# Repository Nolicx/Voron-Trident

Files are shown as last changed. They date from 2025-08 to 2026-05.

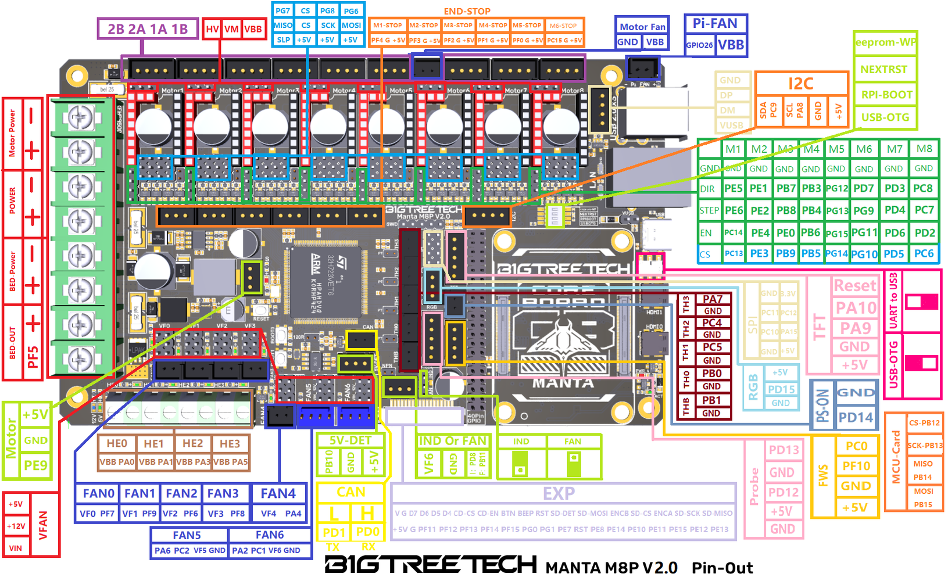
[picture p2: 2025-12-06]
BIGTREETECH MANTA M8P V2-0 PinOut.png

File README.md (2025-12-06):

# Voron Trident Formbot Kit

[Kit Website](https://www.formbot3d.com/products/voron-trident-r1-pro-corexy-3d-printer-kit-with-best-quality-parts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)

# Overview

* [Build Notes](https://github.com/FORMBOT/Voron-Trident/tree/main/Build%20Notes)
* [Firmware Flashing](https://github.com/FORMBOT/Voron-Trident/tree/main/Firmware%20Flashing)
* [Config Setup and Initial Startup](https://github.com/FORMBOT/Voron-Trident/tree/main/Config)
* Maintenance
* [STLs](https://github.com/FORMBOT/Voron-Trident/tree/main/STL)
* Printer Tuning
* Printer Testing

## CAN Network Issue
* https://github.com/systemd/systemd/issues/30947
* https://github.com/linux-can/can-utils/issues/68

## CAN Setup
* https://drklipper.de/doku.php?id=klipper_faq:klipper_0_auf_100:btt_cb1_manta_m8p_sb2209

## Voronica Config
* https://github.com/cee-wals/voronica-configs/blob/main/voronica-bigtreetech-manta-m8p-voron2.cfg

## Manta M8P V2.0 Pins
* https://meltbro.de/images/product_images/original_images/BIGTREETECH%20MANTA%20M8P%20V2-0%20PinOut.png

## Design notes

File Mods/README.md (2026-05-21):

# Voron Trident Mods

## Gridfinity holder for Voron printers (2020 extrusion)

### Gridfinity holder for Voron printers (2020 extrusion)
[Printables](https://www.printables.com/model/175108-gridfinity-holder-for-voron-printers-2020-extrusion)

* Gridfinity-Behälter an 2020-Profilen befestigen — modulares Organizer-System für Werkzeug und Kleinteile.

### Gridfinity mount for 2020 extrusions
[Printables](https://www.printables.com/model/431489-gridfinity-mount-for-2020-extrusions-voron-printer)

* ✅ installiert
* Alternativer Gridfinity-Mount für 2020-Profile, speziell für Voron-Drucker ausgelegt.

---

## Panels

### Voron 2.4/Trident Magnetic Panels with Magnet Inserts
[Printables](https://www.printables.com/model/775808-voron-24r2trident-magnetic-panels-with-magnet-inse)

* ✅ installiert
* Seitenpanele mit Magneten statt Clips — lassen sich schnell und werkzeuglos abnehmen.

### Sturdy Print-in-Place Panel Latch for 2020 Extrusion
[Printables](https://www.printables.com/model/1042802-sturdy-print-in-place-panel-latch-for-2020-extrusi/related)

* Robuster Print-in-Place Panel-Riegel für 2020-Profile als Alternative zu Clips.

---

## Magnetic Hinges

### Voron Magnetic Door Hinges Enhanced
[Printables](https://www.printables.com/model/899914-voron-magnetic-door-hinges-enhanced)

* ✅ installiert
* Verbesserte Türscharniere mit Magneten für einen saubereren Öffnungs- und Schließmechanismus.

---

## Frame

### Parametric Voron Frame Brace
[Printables](https://www.printables.com/model/1270452-parametric-voron-frame-brace)

* Parametrische Rahmenversteifung an den Ecken — reduziert Vibrationen und verbessert die Resonanzqualität.

### 2020 Top Corner for Voron 2.4 / Trident
[Printables](https://www.printables.com/model/1354277-2020-top-corner-for-voron-24-trident)

* Ersatz-Eckverbinder für die oberen 2020-Profile.

### Voron Simplified Corners
[Printables](https://www.printables.com/model/1643589-voron-simplified-corners)

* Vereinfachte Ecken für den Voron-Rahmen — cleaner Look, gleiche Funktion.

---

## Auxiliary Fans

### Auxiliary Fans
[Thingiverse](https://www.thingiverse.com/thing:6122197)

* ✅ installiert
* Zusätzliche Lüfter zur Kammerbelüftung, montiert an DIN-Schienen via Klipper Expander gesteuert.

### Klipper Expander
[GitHub](https://github.com/VoronDesign/Voron-Hardware/tree/master/Klipper_Expander)

* ✅ installiert
* Erweiterungsboard für zusätzliche Klipper-Ausgänge (z. B. Lüftersteuerung).

### Klipper Expander DIN Rail Adapter
[Printables](https://www.printables.com/model/425248-klipper-expander-din-rail-adapter)

* ✅ installiert
* DIN-Schienen-Adapter für den Klipper Expander.

### PCB DIN Clip x3 (Formbot)
[GitHub](https://github.com/FORMBOT/Voron-Trident/blob/main/STL/ElectronicsBay/pcb_din_clip_x3.stl)

* ✅ installiert
* DIN-Schienen-Clips zur Befestigung von PCBs (Formbot-spezifisch, 3er-Set).

---

## Lighting

### Voron Daylight
[GitHub](https://github.com/VoronDesign/Voron-Hardware/blob/master/Daylight/README.md)

* ✅ installiert
* Voron Daylight LED-Leisten für gleichmäßige Kammerausleuchtung.

---

## Exhaust Cover

### Voron 2.4 Exhaust Cover
[Printables](https://www.printables.com/model/412144-voron-24-exhaust-cover)

* ✅ installiert
* Abdeckung für den Abluftbereich — schließt die Öffnung sauber ab wenn kein Filter verbaut ist.

---

## Preloaded Lead Screw Nuts

### Voron Trident Z-Axis Mods for Preloaded Lead Screw Nuts
[Printables](https://www.printables.com/model/1232008-voron-trident-z-axis-mods-for-preloaded-lead-screw)

* ✅ installiert
* Z-Achsen-Spindelmuttern mit Federvorspannung — eliminiert Spiel in der Z-Achse für präzisere erste Schicht.

---

## Thermistor Mounts

### NTC 100k 3950 Glass Thermistor Mount (2020 extrusion)
[Printables](https://www.printables.com/model/805687-ntc-100k-3950-glass-thermistor-mount-2020-extrusio)

* Halterung für NTC-100k-Glasthermistor an 2020-Profil — Kammertemperaturmessung.

### NTC 100k 3950 Glass Thermistor Chamber Sensor Mount
[Printables](https://www.printables.com/model/1330198-ntc-100k-3950-glass-thermistor-chamber-sensor-moun)

* ✅ installiert
* Montagehalter für NTC-100k-Glasthermistor als Kammertemperatursensor.

### Voron CW2 Thermistor Holder PCB Cover
[Printables](https://www.printables.com/model/536989-voron-cw2-thermistor-holder-pcb-cover)

* ✅ installiert
* PCB-Abdeckung mit integriertem Thermistorhalter für das Clockwork2-Extruder-System.

---

## Build Plate Stopper

### Voron 2.4 Flex Plate Stops
[MakerWorld](https://makerworld.com/en/models/109337-voron-2-4-flex-plate-stops?from=search)

* ✅ installiert
* Anschläge für die Flex-/PEI-Platte — sorgen für reproduzierbare Positionierung beim Einlegen.

### Trident PEI Plate Mounting Slot
[MakerWorld](https://makerworld.com/en/models/1024379-trident-pei-plate-mounting-slot?from=search#profileId-1006303)

* ✅ installiert
* Einschubführung für PEI-Druckplatten am Voron Trident.

---

## Inverted Electronics

### Inverted Electronics
[Voron Mods](https://mods.vorondesign.com/details/pXkXHVIUbqSWqQKJISczw)

* ✅ installiert
* Elektronikboden wird umgekehrt eingebaut — bessere Zugänglichkeit und Wärmetrennung vom Druckraum.

### Trident Inverted Electronics Deck Handle
[Printables](https://www.printables.com/model/933809-trident-inverted-electronics-deck-handle)

* ✅ installiert
* Griff für den invertierten Elektronikboden — erleichtert das Entnehmen des Decks.

### DIN Rail Wire Channel Support
[Printables](https://www.printables.com/model/782718-din-rail-wire-channel-support-voron-trident-invert)

* ✅ installiert
* Kabelkanalhalter für DIN-Schiene bei invertiertem Elektronikboden.

### Trident Inverted Electronics Slip-In Bracket
[Printables](https://www.printables.com/model/883096-voron-trident-inverted-electronics-slip-in-bracket)

* ✅ installiert
* Einschubhalter für Elektronikkomponenten beim invertierten Deck.

### Spacer for Inverted Electronics (Noctua)
[Printables](https://www.printables.com/model/253265-voron-trident-spacer-for-inverted-electronics-noct)

* ✅ installiert
* Abstandshalter für Noctua-Lüfter beim invertierten Elektronikboden.

### BTT M8P V2.0 Cooling 2x4010
[Printables](https://www.printables.com/model/891446-btt-m8p-v20-cooling-2x4010)

* ✅ installiert (ersetzt durch das untere)
* Kühlgehäuse für das BTT Manta M8P mit 2× 40-mm-Lüftern.

### Manta Rays – BTT Manta M8P Fan Case
[Printables](https://www.printables.com/model/1181320-manta-rays-btt-manta-m8p-fan-case/files)

* ✅ installiert
* Verbessertes Lüftergehäuse für das BTT Manta M8P — bevorzugte Alternative zum obigen Modell.

---

## Nozzle Scrubber

### Trident Decontaminator/Nozzle Scrubber Wiper (Bambu)
[Printables](https://www.printables.com/model/904716-trident-decontaminatornozzle-scrubber-wiper-bambu)

* Automatische Düsenreinigung für den Voron Trident — Bambu-kompatible Bürste.

### LDO Trident Mount for Decontaminator Purge Bucket
[Printables](https://www.printables.com/model/889734-ldo-trident-mount-for-decontaminator-purge-bucket)

* Befestigungshalter für den Purge-Eimer am LDO Trident.

### Voron 2.4 Bamboo A1 Brush Bucket
[Printables](https://www.printables.com/model/957985-voron-24-bamboo-a1-brush-bucket)

* ✅ installiert, Macro eingebunden
* Purge-Eimer und Düsenreiniger für den Voron 2.4 — kompatibel mit Bambu-A1-Bürste.

### Voron 2.4 Silicone Nozzle Scrubber w/ Sheet Stops
[Printables](https://www.printables.com/model/796563-voron-24-silicone-nozzle-scrubber-w-sheet-stops-be)

* Silikon-Düsenreiniger mit integrierten Sheet-Stops — das zugehörige Macro ist interessant.

---

## Bambulab Hotend

### Bambu Stealthburner Rear TAP Support
[Printables](https://www.printables.com/model/607566-bambu-stealthburner-rear-tap-support)

* ✅ installiert
* Hintere TAP-Abstützung für den Stealthburner mit Bambu-Hotend.

### Bambu Stealthburner for Stock Bambu Hotend
[Printables](https://www.printables.com/model/550394-bambu-stealthburner-for-stock-bambu-hotend)

* ✅ installiert
* Adapter um das BambuLab-Hotend im Stealthburner zu betreiben — hohe Durchflussrate, einfacher Düsenwechsel.

### CHT High Flow Nozzle for BambuLab (CNC Kitchen)
[CNC Kitchen](https://www.cnckitchen.com/blog/cht-high-flow-nozzle-for-the-bambulab-x1-amp-p1p)

* CHT High-Flow-Düse für das BambuLab-Hotend — erhöht den maximalen Volumenstrom deutlich.

---

## Camera

### HappyCam Voron 2.4 OV5640 Camera Mount
[Printables](https://www.printables.com/model/488020-happycam-voron-24-ov5640-camera-mount)

* ✅ installiert
* Kamerahalterung für OV5640-Modul zur Drucküberwachung via Mainsail/Fluidd.

### Camera Mount (Voron Mods)
[Voron Mods](https://mods.vorondesign.com/details/RYpQW53mtem8Nj1JKqiSQ)

* Alternative offizielle Kamerahalterung aus der Voron-Mods-Sammlung.

---

## FilamATrix

### FilamATrix
[GitHub](https://github.com/thunderkeys/FilamATrix/tree/main)

* Multi-Material-Filamentwechsler — ermöglicht automatischen Filamentwechsel für mehrfarbige Drucke.

---

## Build Plate Holder

### Steel Sheet Holder for Voron 2.4 / Trident
[Printables](https://www.printables.com/model/368691-steel-sheet-holder-for-voron-24-voron-trident-v0)

* Externe Halterung für Reservedruckplatten außen am Drucker.

---

## Filament Runout Sensor

### Voron Filament Runout Sensor
[Printables](https://www.printables.com/model/742887-voron-filament-runout-sensor)

* Sensor erkennt Filamentende und pausiert den Druck automatisch.

---

## HULA

### HULA v1.0 for Voron Printers
[Printables](https://www.printables.com/model/898357-hula-v10-for-voron-printers)

* ✅ installiert
* Hochperformanter Filamentantrieb — verbesserte Gripper-Geometrie für zuverlässigen Vorschub bei hohen Druckgeschwindigkeiten.

### HULA Voron
[GitHub](https://github.com/thrutheframe/HULA_Voron)

* ✅ installiert
* GitHub-Repository zum HULA-Extruder mit Dokumentation und STLs.

---

## Stepper Decoupler

### Voron Trident Stepper Decoupler
[Printables](https://www.printables.com/model/430168-voron-trident-stepper-decoupler)

* ✅ installiert
* Entkoppler zwischen Z-Stepper und Spindel — ermöglicht freies Absinken des Bettes beim Homing ohne Motorwiderstand.

### Double Shear Mounts
[GitHub](https://github.com/gdsolar/Printer-Mods/tree/main/Voron/Double_Shear_Mounts)

* Beidseitig gelagerte Motorhalterungen für reduzierte Biegebelastung auf den Motorwellen.

---

## Front Idlers

### Voron BFI Aesthetic Trident Remix
[Printables](https://www.printables.com/model/1024258-voron-bfi-asthetic-trident-remix)

* ✅ installiert
* Optisch überarbeitete vordere Riemenspanner — gleiche Funktion, cleaner Look.

### Voron Trident WS-1204 WobbleX
[Printables](https://www.printables.com/model/1376982-voron-trident-ws-1204-wobblex)

* WobbleX-Idler für den Voron Trident — reduziert Resonanzartefakte durch dämpfende Lagerung.

### Interfaces for WobbleX Integration
[GitHub](https://github.com/MirageC79/Interfaces-for-WobbleX-integration)

* Adapter-Interfaces zur Integration des WobbleX-Systems in bestehende Voron-Setups.

---

## Side Handles

### Voron 2.4 / Trident Side Handles
[Printables](https://www.printables.com/model/826183-voron-24-trident-side-handles)

* ✅ installiert
* Seitliche Tragegriffe — erleichtern das Anheben und Transportieren des Druckers.

---

## Spool Holders

### Trident Internal Spool Holder for 2020 Extrusion
[Printables](https://www.printables.com/model/584995-trident-internal-spool-holder-for-2020-extrusion/)

* ✅ installiert
* Interne Spulenhalter — Filament wird direkt im Drucker geführt, kurzer Bowden-Weg zum Extruder.

### Trident Simple Internal Spool Holder Bowden Guide 60°
[TeamFDM](https://www.teamfdm.com/files/file/619-trident-simple-internal-spool-holder-bowden-guide-60degrees-curved/)

* ✅ installiert
* 60°-Bowden-Guide für den internen Spulenhalter — sanfte Filamentführung zum Extruder.

### Classic Spool Holder (V2.4/Trident)
[GitHub](https://github.com/elcrni/V2.4-Trident-Spool-Holders/blob/main/STL/Classic__spool_holder.stl)

* ✅ installiert
* Klassischer Spulenhalter für Voron 2.4 und Trident.

### Voron Trident Internal Spool Bowden Tube Bracket
[Printables](https://www.printables.com/model/678821-voron-trident-internal-spool-bowden-tube-bracket/files?lang=de)

* ✅ installiert
* Haltewinkel für den Bowden-Schlauch am internen Spulenhalter.

### Locking Foldable Spool Holder
[Printables](https://www.printables.com/model/542953-locking-foldable-spool-holder-for-voron-v02-0-v0-0)

* Klappbarer Spulenhalter mit Arretierung — platzsparend wenn nicht in Benutzung.

---

## KNOMIv2

### KNOMI v2
[GitHub](https://github.com/bigtreetech/KNOMI)

* ✅ installiert
* BTT KNOMI v2 Display am Toolhead — zeigt Druckstatus, Temperaturen und Fortschritt direkt am Druckkopf an.

---

## PSU Cover

### PSU Cover
[Voron Mods](https://mods.vorondesign.com/details/jyO8bHoPTy3XUaYlXscB7w)

* Schutzabdeckung für die Netzteilklemmen — verhindert versehentlichen Kontakt mit spannungsführenden Teilen.

---

## Rainbow Serial Bumper

### Rainbow Serial Bumper
[Voron Mods](https://mods.vorondesign.com/details/dpPGVV98ROfSC1Kmu16MEg)

* Dekorativer Bumper für die Seriennummer — schützt die Serienaufschrift und wertet die Optik auf.

---

## PTFE Bowden Guide

### Voron Bowden PTFE Tube Guide Arm and CAN Bus Cable
[Printables](https://www.printables.com/model/978123-voron-bowden-ptfe-tube-guide-arm-and-canbus-cable)

* ✅ installiert
* Führungsarm für PTFE-Schlauch und CAN-Bus-Kabel — ordentliches Kabelmanagement am Toolhead.

---

## Nevermore Mount

### Trident Nevermore Bed Mount
[GitHub](https://github.com/Outrider305/Trident_Nevermore_Bed_Mount/blob/6f0d5977b592f5feb3b60df2ecaaecfb3d4709c4/STLs/Trident_Bed_Mount_Bracket_Right.stl)

* ✅ installiert
* Halterung für den Nevermore-Aktivkohlefilter am Bett — filtert VOCs und Gerüche direkt aus der Druckkammer.

---

## Formbot R1

### BTT HDMI5 V1.2 Display Mount Voron
[Printables](https://www.printables.com/model/926845-btt-hdmi5-v12-display-mount-voron)

* Halterung für das BTT HDMI5 V1.2 Display am Voron-Rahmen.

### Voron Trident Wire Cover w/ PG7 Cable Gland Adapter
[Printables](https://www.printables.com/model/326623-voron-trident-wire-cover-w-pg7-cable-gland-adapter/files)

* Kabelabdeckung mit PG7-Kabelverschraubungsadapter für sauberes Kabelmanagement.

### PG7 / Cnlinko LP-12 Mount for SB2209/SB2240
[Printables](https://www.printables.com/model/464735-pg7-cnlinko-lp-12-mount-for-sb2209-sb2240)

* Halterung für PG7- oder Cnlinko-LP-12-Steckverbinder am SB2209/SB2240.

### Voron Trident Fixed Nozzle Scrubber (Remixes)
[Printables](https://www.printables.com/model/413177-voron-trident-fixed-nozzle-scubber/remixes)

* Fester Düsenreiniger für den Voron Trident — diverse Remixes für verschiedene Setups.

---

## Clicky-Clack Fridge Door

### Clicky-Clack Fridge Door
[GitHub](https://github.com/tanaes/whopping_Voron_mods/tree/main/clickyclacky_door)

* Kühlschranktür-Umbau für den Voron — magnetisch verriegelnde Fronttür mit charakteristischem Klappmechanismus.

### Clicky-Clack Fridge Door – Voron Logo Handle
[Printables](https://www.printables.com/model/849495-clicky-clack-fridge-door-voron-logo-handle/files)

* Türgriff mit Voron-Logo für die Clicky-Clack-Tür.

### Voron Fridge Door Light Switch
[MakerWorld](https://makerworld.com/en/models/2519870-voron-fridge-door-light-switch?from=search#profileId-2772082)

* Lichtschalter-Mechanismus für die Clicky-Clack-Tür — schaltet die Kammerbeleuchtung beim Öffnen.

### Thicc Skirts for Voron Clicky-Clack Fridge Door
[Printables](https://www.printables.com/model/961366-thicc-skirts-for-voron-clicky-clack-fridge-door/)

* Verstärkte Skirts kompatibel mit dem Clicky-Clack-Tür-Umbau.

### BTT HDMI 5 Display Voron Mount (Clicky-Clack compatible)
[Printables](https://www.printables.com/model/861544-btt-hdmi-5-display-voron-mount-works-with-clicky-c/remixes)

* Display-Halterung für das BTT HDMI 5, kompatibel mit der Clicky-Clack-Tür.

### BTT HDMI5 V1.2 Display Mount Voron
[Printables](https://www.printables.com/model/926845-btt-hdmi5-v12-display-mount-voron/files)

* Offizielle Halterung für das BTT HDMI5 V1.2 Display.

---

## Skirt

### Plug-in Mesh Inserts for Voron Trident Skirts
[Printables](https://www.printables.com/model/1275963-plug-in-mesh-inserts-for-voron-trident-skirts/files)

* Einsteckbare Gitter-Einsätze für die Voron-Trident-Skirts — verbesserte Optik und Belüftung.

### Modular Mesh Inserts for Voron Fan Grille
[Printables](https://www.printables.com/model/931612-modular-mesh-inserts-for-the-voron-fan-grille/files)

* Modulare Gittereinsätze für die Voron-Lüftergitter.

---

## Wago Mounts

### Extended Wago Mount – Voron Trident
[Printables](https://www.printables.com/model/928966-extended-wago-voron-trident/files)

* Verlängerter Halter für Wago-Klemmen im Voron Trident.

### Double Wago 221-413 for 2020 Profile – Voron Trident
[Printables](https://www.printables.com/model/1716086-double-wago-221-413-for-2020-profile-voron-trident)

* Doppelhalter für Wago 221-413 Klemmen an 2020-Profilen.

### Wago Mount for Voron V0
[Printables](https://www.printables.com/model/723488-wago-mount-for-voron-v0/files)

* Wago-Klemmenhalter ursprünglich für den Voron V0, ggf. adaptierbar.

---

## Nevermore

### Nevermore Micro V6
[GitHub](https://github.com/nevermore3d/Nevermore_Micro/tree/master/V6)

* Nevermore Micro V6 — kompakter Aktivkohlefilter für die Druckkammer zur VOC- und Geruchsfilterung.

---

## General

- [Trident Mods Collection (pila81)](https://github.com/pila81/Trident_Mods)
- [Voron Build Startup](https://docs.vorondesign.com/build/startup/)
- [Voron Slicer Setup](https://docs.vorondesign.com/build/slicer/)
- [Voron Secondary Printer Tuning](https://docs.vorondesign.com/tuning/secondary_printer_tuning.html)
- [Ellis3DP Print Tuning Guide](https://ellis3dp.com/Print-Tuning-Guide/)

---

## Macros

- [Ellis3DP Useful Macros](https://ellis3dp.com/Print-Tuning-Guide/articles/index_useful_macros.html)
- [Voron 120 Decibel Macro](https://docs.vorondesign.com/community/macros/macros/120decibell.html)
- [Decontaminator Purge Bucket & Nozzle Scrubber Macro](https://github.com/edwardyeeks/VoronUsers/blob/master/printer_mods/edwardyeeks/Decontaminator_Purge_Bucket_%26_Nozzle_Scrubber/Macros/sample_nozzle_scrub_menu.cfg)
- [Voron Trident 250 Macros Config](https://github.com/rcg94/voron-trident-250-20241017/blob/main/macros.cfg)

---

## Klipper Extensions

- [klipper-virtual_leds](https://github.com/MapleLeafMakers/klipper-virtual_leds)
- [klipper-led_effect](https://github.com/julianschill/klipper-led_effect)
- [klipper_tmc_autotune](https://github.com/andrewmcgr/klipper_tmc_autotune)
- [chopper-resonance-tuner](https://github.com/MRX8024/chopper-resonance-tuner)
- [klippain-shaketune](https://github.com/Frix-x/klippain-shaketune)
- [Klipper Adaptive Meshing & Purging](https://github.com/kyleisah/Klipper-Adaptive-Meshing-Purging)

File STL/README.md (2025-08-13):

# Notes
STLs are tried to be kept up to date.
Original Repos: 
https://github.com/VoronDesign/Voron-Trident
https://github.com/VoronDesign/Voron-Stealthburner
https://github.com/VoronDesign/Voron-Tap
https://github.com/bigtreetech/EBB/tree/master/EBB%20SB2209%20CAN%20(RP2040)
https://github.com/nevermore3d/Nevermore_Micro/tree/master/V5_Duo
and some specific parts ;)

# Filename Nomenclature

| Filename | Note |
|---|---|
| \*.stl | Base color |
| [a]\_\*.stl | Accent color |
| [o]\_\*.stl | Opaque (light doesn't penetrate) |
| [c]\_\*.stl | Clear/Translucent (light can penetrate) |

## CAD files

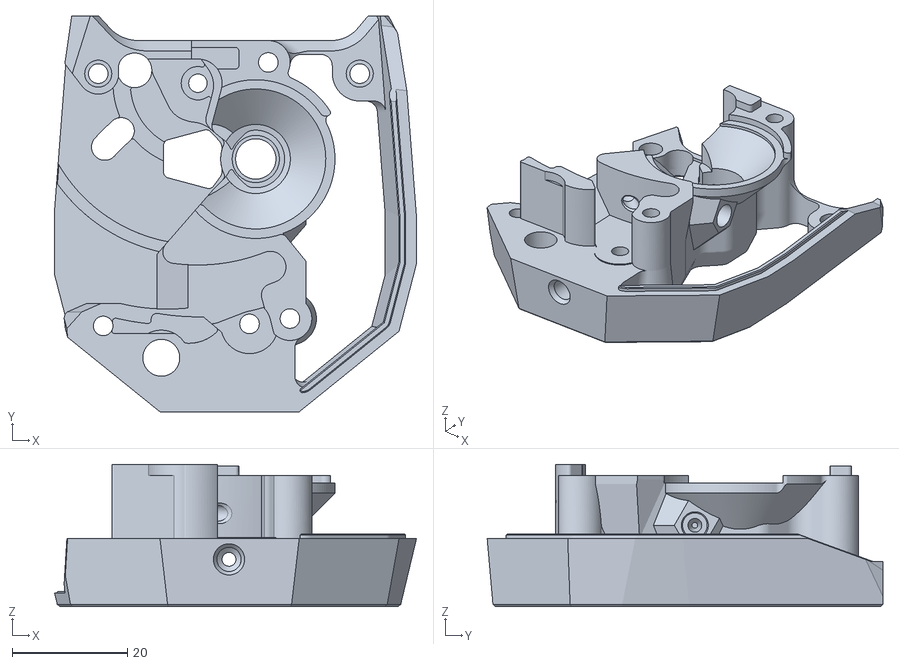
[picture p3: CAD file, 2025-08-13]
STL/Stealthburner/Clockwork2/Direct_Drive/main_body.stl
62.8 x 68.7 x 24.7

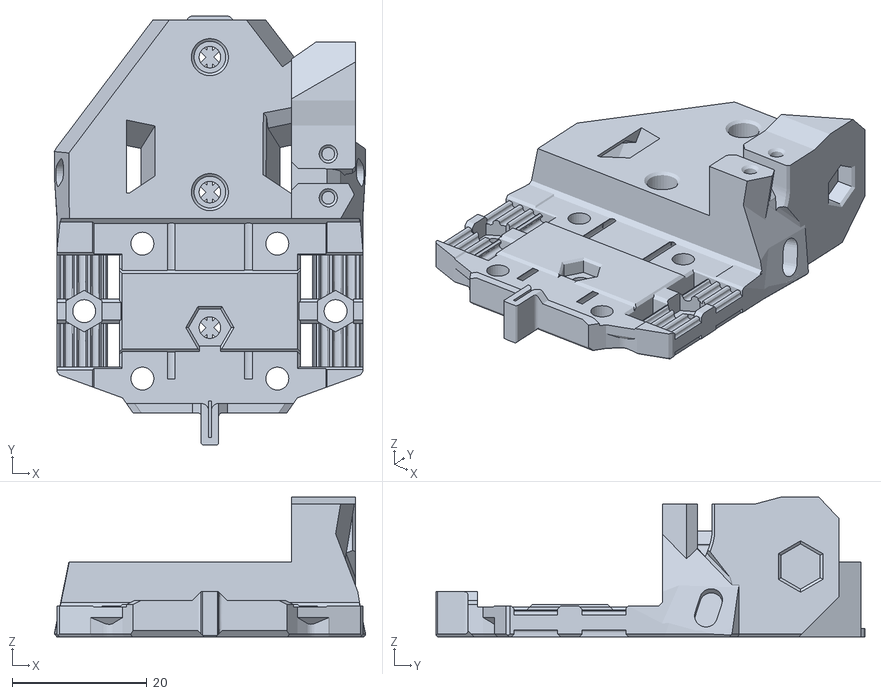
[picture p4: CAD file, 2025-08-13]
Mods/[a]_Tap_Center_r8.stl
46.2 x 63.6 x 20.7

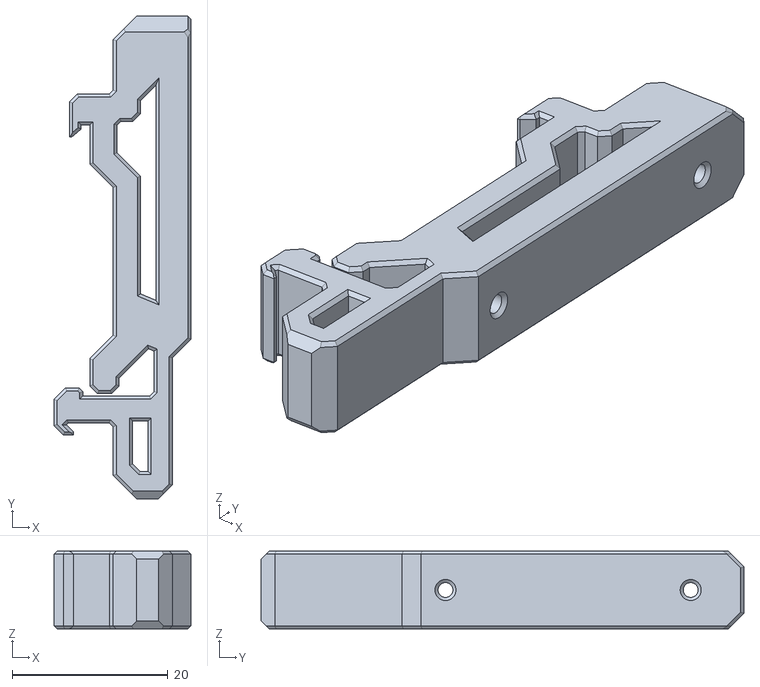
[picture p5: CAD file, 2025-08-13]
Mods/auxiliary_fans/pcb_din_clip_x3.stl
17.6 x 62.0 x 10.0

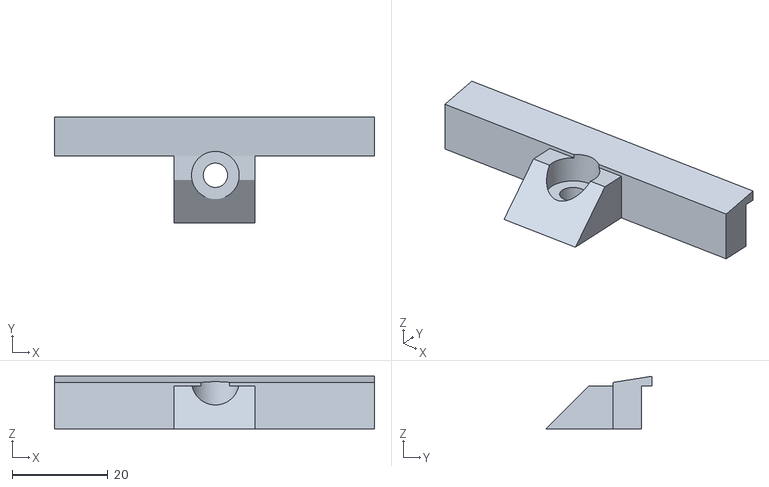
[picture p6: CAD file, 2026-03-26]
Mods/build_plate_stopper/PEI.stl
67.0 x 22.2 x 11.0

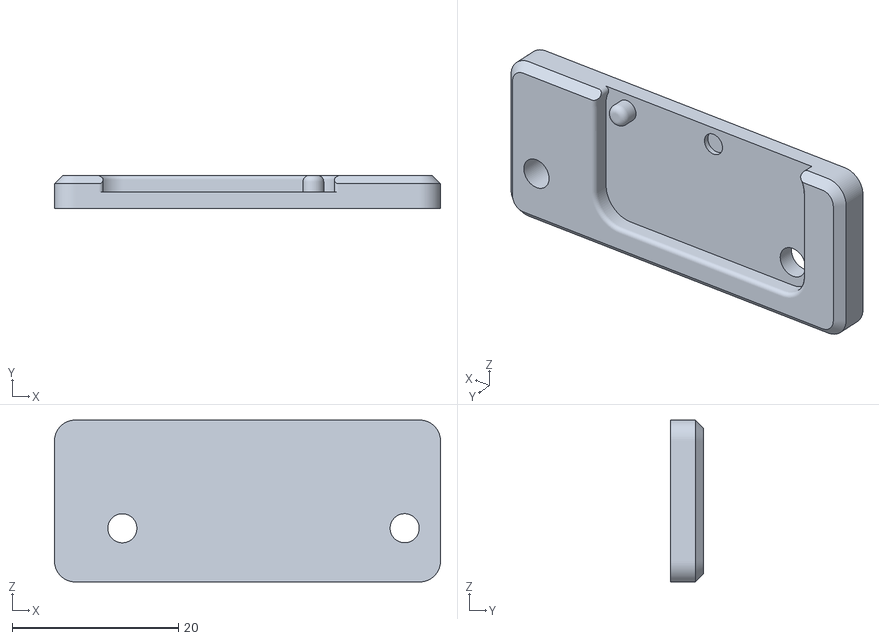
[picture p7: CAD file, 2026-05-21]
Mods/door/Voron+Fridge+Door+Light+Switch.stl
46.5 x 4.00 x 19.5

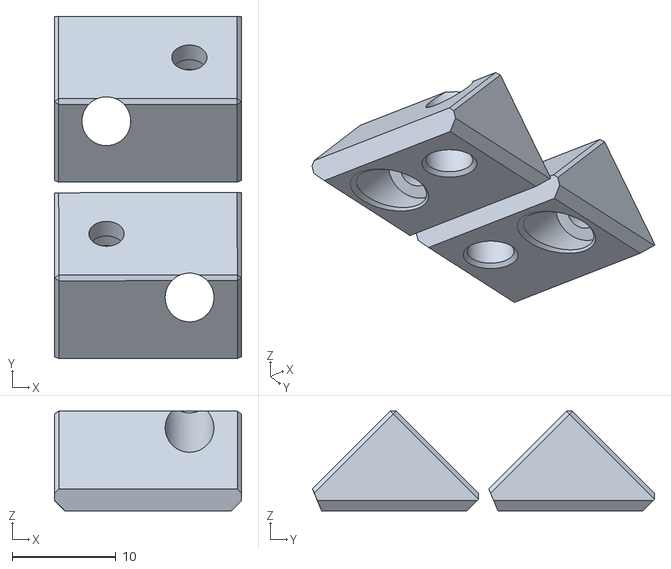
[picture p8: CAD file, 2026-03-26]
Mods/lighting/Brackets_2020.stl
18.0 x 33.0 x 9.62

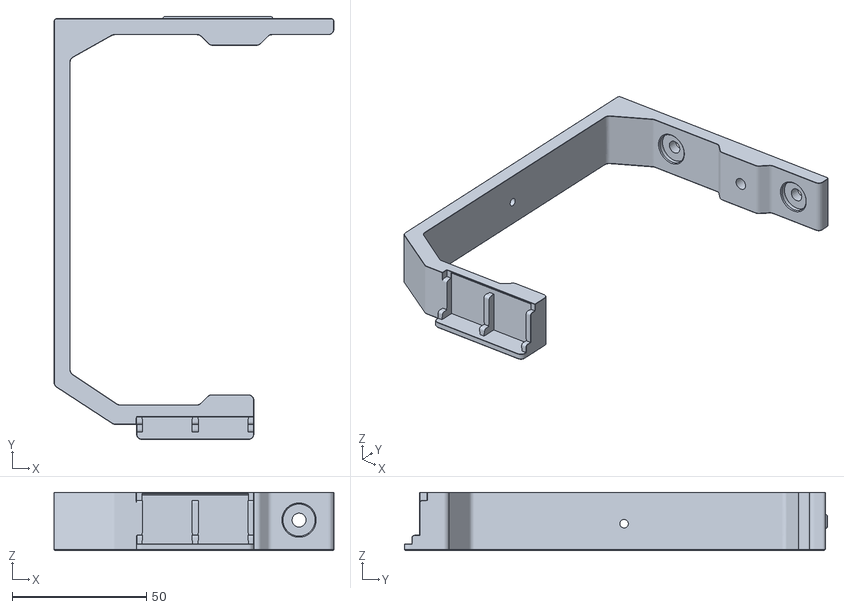
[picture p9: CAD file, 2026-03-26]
Mods/nevermore_mount_v1/Trident_Bed_Mount_Bracket_Right(1).stl
104.3 x 157.7 x 21.8

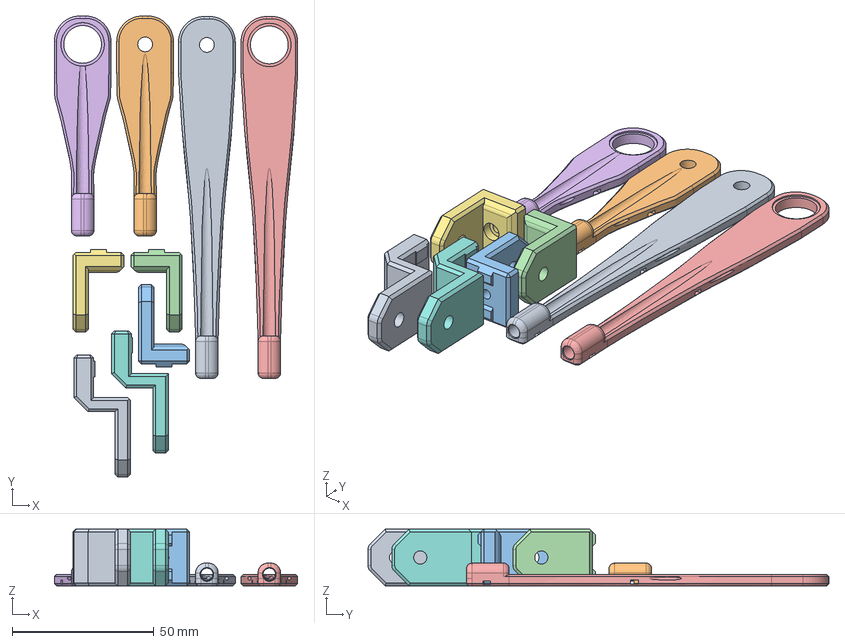
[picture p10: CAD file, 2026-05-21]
Mods/ptfe_bowden_guide/voron-bowden-ptfe-tube-guide-arm-and-canbus-cable-support-model_files/CAD/bowden_guide-v2.step
85.8 x 162.4 x 20.0 mm
Long_Arm
Mount v1
Mount
Mount_Bearing
Long Arm Bearing
Short_Arm_Bearing
Low_Mount_Bearing
Under_extrusion_mount_bearing
Under_extrusion_mount

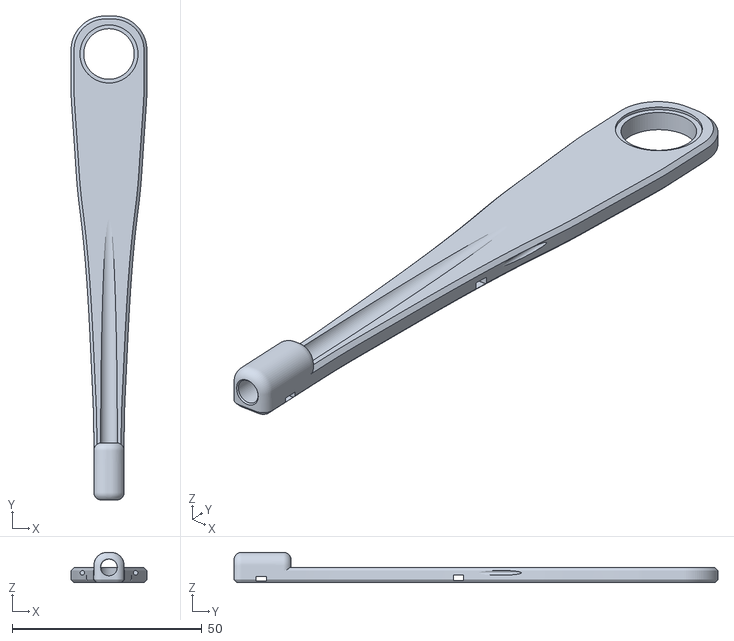
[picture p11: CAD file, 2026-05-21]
Mods/ptfe_bowden_guide/voron-bowden-ptfe-tube-guide-arm-and-canbus-cable-support-model_files/STL's/long-arm-bearing.stl
20.0 x 127.5 x 8.00

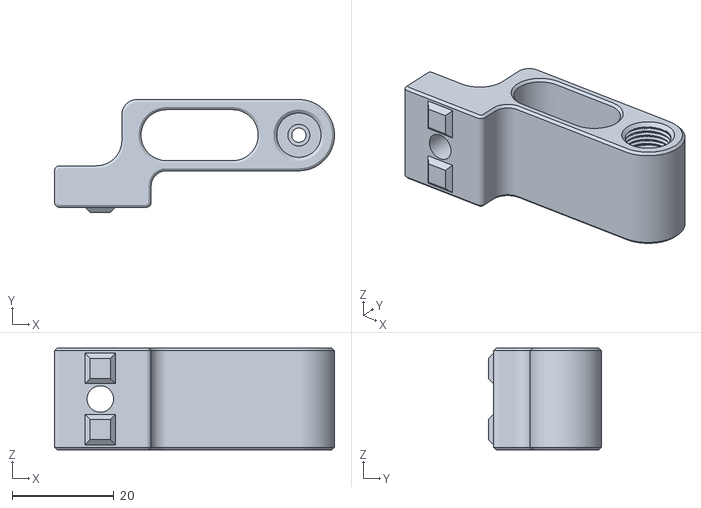
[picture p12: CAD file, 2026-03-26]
Mods/spool_holders/trident pass through bowden coupler mount..stl
55.0 x 22.2 x 20.0

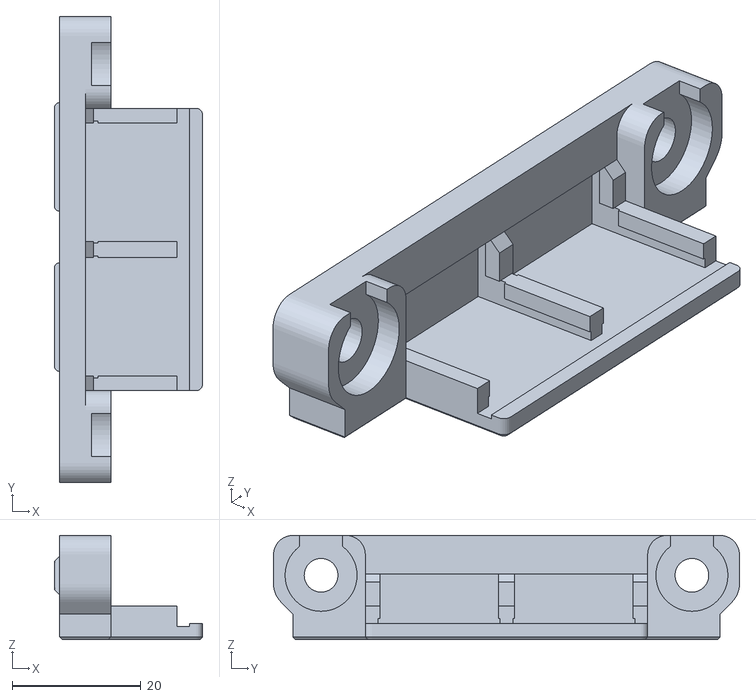
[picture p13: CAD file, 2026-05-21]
Mods/wago_mounts/wago_221-413_mount.stl
23.0 x 72.5 x 16.2

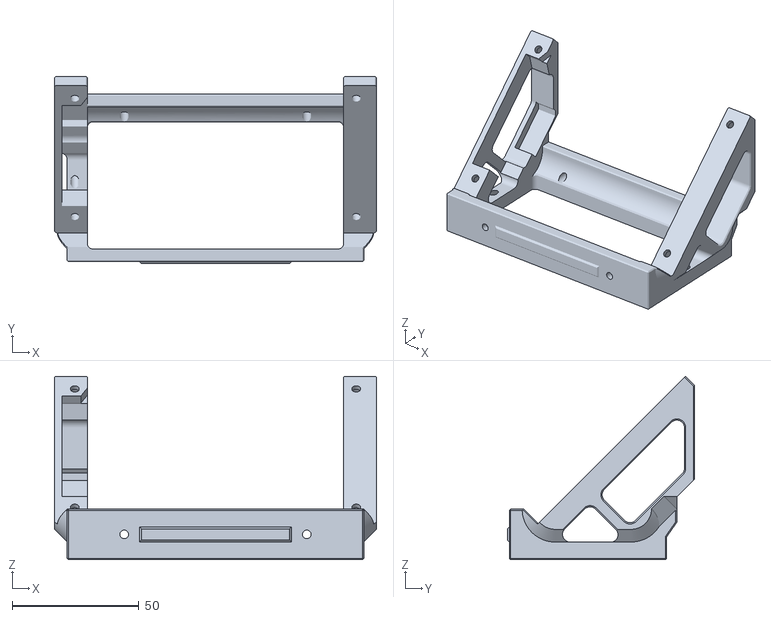
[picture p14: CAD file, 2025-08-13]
only custom STLs/Accent/BTT HDMI5 V1_2 mount bracket_Regular.stl
127.0 x 73.8 x 72.4

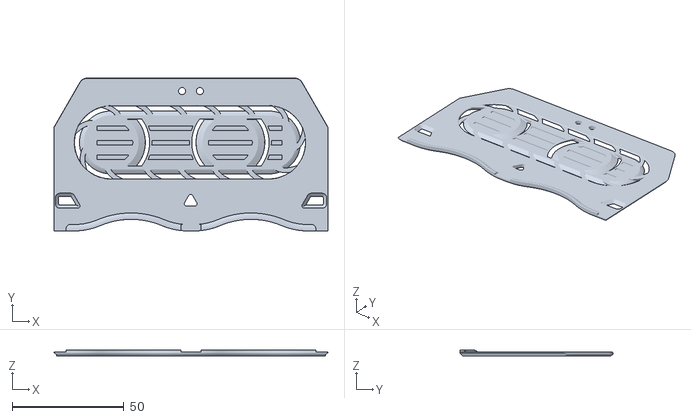
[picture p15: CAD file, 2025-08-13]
only custom STLs/Primary/Nevermore/Trident_Bed_Mount_Plenum_Lid_r1.stl
122.8 x 68.5 x 2.80

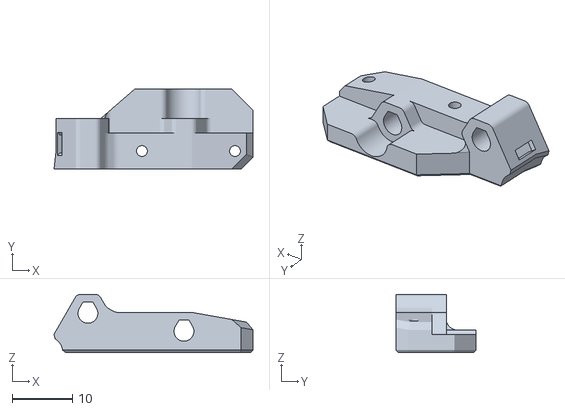
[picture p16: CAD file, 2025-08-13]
only custom STLs/Primary/sb_adxl_mount_generic_15.5mm_c_c.stl
33.2 x 13.4 x 9.70

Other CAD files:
STL/ElectronicsBay/DIN_frame_mount_x4.stl
STL/Exhaust_Filter/exhaust_filter_housing.stl
STL/Gantry/AB_Drive_Units/[a]_y_endstop_housing.stl
STL/Gantry/Front_Idlers/front_idler_a_x2.stl
Mods/build_plate_stopper/Flex+Plate+Stops.stl
Mods/ptfe_bowden_guide/voron-bowden-ptfe-tube-guide-arm-and-canbus-cable-support-model_files/CAD/bowden_guide-v2.f3d
Mods/ptfe_bowden_guide/voron-bowden-ptfe-tube-guide-arm-and-canbus-cable-support-model_files/STL's/long_arm.stl
Mods/ptfe_bowden_guide/voron-bowden-ptfe-tube-guide-arm-and-canbus-cable-support-model_files/STL's/low_mount_bearing.stl
Mods/ptfe_bowden_guide/voron-bowden-ptfe-tube-guide-arm-and-canbus-cable-support-model_files/STL's/mount.stl
Mods/ptfe_bowden_guide/voron-bowden-ptfe-tube-guide-arm-and-canbus-cable-support-model_files/STL's/mount_bearing.stl
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

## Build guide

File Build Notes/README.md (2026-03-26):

## Functional parts build notes (to get the Printer up and running)

Start with the [Stock Voron Trident manual](https://github.com/VoronDesign/Voron-Trident/blob/main/Manual/Assembly_Manual_Trident.pdf).

Be aware that the vT Manual uses a 250mm Version of the Trident, so some dimensions may seem wrong if you build a 300mm/350mm Version.

### P. 48 Trident manual:

Skip this step, we use physical endstops and no hall effect ones.

### P. 56-60 Trident manual:

If you are building a 300mm machine you will need to start you screws from the second screw hole in the rails leaving the end holes open to allow space for T-nuts at later steps. Small reminder: The carriages are designed to slide along the rail easily. This unfortunately also includes sliding off the rails. Dropping the carriage likely irreparably damages it. ALWAYS put the little black rubber Carriage stoppers back on the rail (into the holes without screws) until your printer ist up and runnning!

### P. 100-101 Trident manual:

Skip these steps, you wont use either the inductive probe or a Cable chain on XY.

### P. 111 Trident manual:

Again, if you are building a bigger printer than the 250mm version, start at the outer holes and screw the rail down every second hole. Small reminder (again): The carriages are designed to slide along the rail easily. This unfortunately also includes sliding off the rails. Dropping the carriage likely irreparably damages it. ALWAYS put the little black rubber Carriage stoppers back on the rail (into the holes without screws) until your printer ist up and runnning!

### P.114 Trident manual:

Install all 4 screws on the right XY Joint.

### P. 115 Trident manual:

Leave this step out, you dont use a cable chain on X and Y.

### P. 122-123 Trident manual:

You use a different X carriage / Probe. Fix the belts with some tape and proceed with the belt Routing. After you routed the belts, fix them on the other side with some tape as well.

### P. 131-133 Trident manual:

Skip these steps, you will do it later after tap is assembled.

### P. 133 Trident manual:

X Carriage: After finishing the AB-Belts Routing, switch to the [TAP Manual](https://github.com/VoronDesign/Voron-Tap/tree/main/Manual). Optotap is used as the sensor.

Be sure to take a look into the R8\_errata.md document, it Highlights some important changes from the Manual and install the X Endstop switch.

### P. 33 Tap Manual:

After you have installed Tap successfully and have the AB belts fixed in the tap carriage, switch to page 134 of the Trident Manual.

### P. 135-137 Trident manual:

Skip these steps since you don't use the stock X carriage but instead you use tap.

### P. 144-145 \& 159 Trident manual:

You don't use this endstop. Your endstop is Tap.

### P. 162/163 Trident manual:

Switch to the [Stealthburner manual](https://github.com/VoronDesign/Voron-Stealthburner/tree/main/Manual).

### P. 13 Stealthburner manual:

You use a Toolhead PCB, so install these two heat inserts.

### P. 14 Stealthburner manual:

Skip

### P. 30 Stealthburner manual:

Follow [this Video Guide](https://www.youtube.com/watch?v=ly22qmB3NxE&t=1s) on how to set the gear mesh on your CW2.

Follow [this video Guide](https://www.youtube.com/watch?v=L1gxBCiE0pk) on how to set the Anti-Squish as well.

### P. 31 Stealthburner manual:

Skip for now, we will install our Version of the Anchor later.

### P. 34 Stealthburner manual:

You dont need to fix the Cable Cover down with the m3x6 BHCS now, you will need to access this later.

### P. 36-43 Stealthburner manual:

All Hotends are mounted in a similar pattern and pretty self-explaining, your hotend mount and hotend will look different.

### P. 46-51 Stealthburner manual:

Be very careful with the cables, you can easily rip them off the LED PCB which leads to this LED and the following ones not working.

### P. 53 Stealthburner manual:

Be sure that your fan blows in the right Direction. Look at the arrows on the fan. Additionally, the Sticker on the fan is on the back pointing towards the Hotend. You want the fan to blow air into the hotend, not trying to pull the air out. This destroys your fan and your whole hotend mount because of heatcreep.

### P. 56 Stealthburner manual:

You dont need to screw the 5015 fan into the SB Face, you will install the SB0000 Fan PCB there later.

### P. 58 Stealthburner manual:

All parts of the Stealthburner are now pretty much finished. Now you will need to install the Can-Board on there and do some basic wiring. Switch to the [SB2209 RP2040 Manual](https://github.com/bigtreetech/EBB/tree/master/EBB%20SB2209%20CAN%20(RP2040)/Build%20Guide).

### P. 02 SB2209 manual:

Now you need to screw down the 5015 fan with the SB0000 PCB :)

### P. 03/04 SB2209 manual:

You need to select Vin (24V) for all fans. Be sure to wire Gnd to Gnd and 24V to 24V! Otherwise you will experience magic smoke later.

### P. 05 SB2209 manual:

Skip

### P. 06 SB2209 manual:

Be sure to wire Gnd to Gnd, Signal to Signal and 24V to 24V! Otherwise you will experience magic smoke later.

### P. 13 SB2209 manual:

You Need to set the switch to 1: on; 2: on; 3: off; 4: on

### P. 15 SB2209 manual:

Skip

### P. 16 SB2209 manual:

Be sure to use the endstop labeled "To CAN\_Endstop" which is the one with the short wires.

### P. 18 SB2209 manual:

Skip

### P. 19 SB2209 manual:

Skip, Stealthburner will be assembled later.

### P. 24 SB2209 manual:

You will need to Strip down the Isolation a bit so you have enough cable length to connect the cable to the PSU and to the Can port. Go back to the Tap Manual page 34 now, flashing the toolhead will be done later.

Use the tight cable sleeve around the cable.

### P. 36 Tap manual:

Stealthburner and Tap are now completed and installed. Switch back to p. 164 of the original Trident manual.

### P. 173 Trident manual:

Rotate the din rails 90° compared to the original layout.

### P. 181-183 Trident manual:

Skip; Raspberry Pi mounting and 5v PSU mounting is not needed. Instead, mount the CB1 / CM4 on the Manta.

### P. 191 Trident manual:

You use the 3in6 Power Distributor instead.

### P. 195 Trident manual:

another small reminder, you don't use a 5v PSU.

### P. 196 Trident manual:

small reminder, you dont use a Raspberry Pi.

### P.198-200 Trident manual:

Skip; TAP is your Z-Endstop, your X Endstop sits on Tap and your Y endstop will be mounted on the A Motor mount later.

### P. 202-205 Trident manual:

Skip these steps, instead configure your Manta like this:

[M8P\_v2 Jumper / Driver marking](https://github.com/FORMBOT/Voron-Trident/blob/main/Diagrams/M8P_config.pdf)

Place a Jumper on all yellow marked pins and place the TMC2209s with attached heatsink on all driver ports with a blue circle after installing the jumpers.

### P. 210/211/216 Trident manual:

Leave the cables to the 5v PSU out.

### P. 217 Trident manual:

Skip, you dont use a standart Raspberry.

### P. 218 Trident manual:

The Z-Endstop cables are not needed.

### P. 218-219/221-231/233-237 Trident manual:

For a better Overview of the wiring, use the [wiring diagram](https://github.com/FORMBOT/Voron-Trident/blob/main/Diagrams/Wiring%20Diagram%20of%20Trident%20R1%20Pro.pdf).

Connect the B motor (left motor) to X Motor, connect the A motor (right motor) to Y Motor.

Connect the CAN-Cable to the right CAN-Port on the M8P and 24V / GND to the 24V PSU. If you think the cables are not Long enough, you haven't done [this step](https://github.com/FORMBOT/Voron-Trident/tree/main/Build%20Notes#p-24-sb2209-manual).

### P. 232 Trident manual:

Route the Y Endstop cable and the A Motor cables down like the B Motor cable (but on the right side of the printer).

### P. 242-244/257 Trident manual:

Skip these steps and instead mount the klipperscreen.

### P. 258 Trident manual:

Don't close the electronics compartment yet, you will need to acces this while flashing the boards.

### P. 281 Trident manual:

Use the big cable sleeve around the exhaust fan cable (if you use the stock exhaust).

#### Don't power on the printer if you are not 100% sure you wired everything correct! And have a look into [this](https://github.com/FORMBOT/Voron-Trident/blob/main/Diagrams/Instruction%20of%20Trident%20R1%20Pro.pdf).

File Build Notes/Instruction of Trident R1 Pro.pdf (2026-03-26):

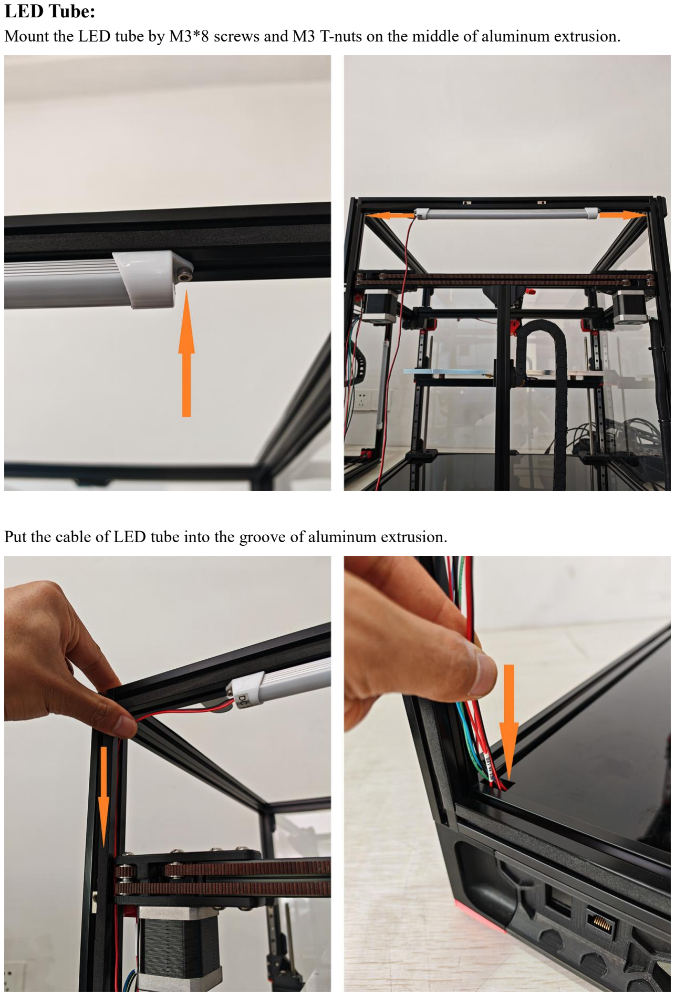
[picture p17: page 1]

LED Tube:
Mount the LED tube by M3*8 screws and M3 T-nuts on the middle of aluminum extrusion.

Put the cable of LED tube into the groove of aluminum extrusion.

Plug the cable onto mainboard as showed below, the red wire to “+”, the black wire to “-”.

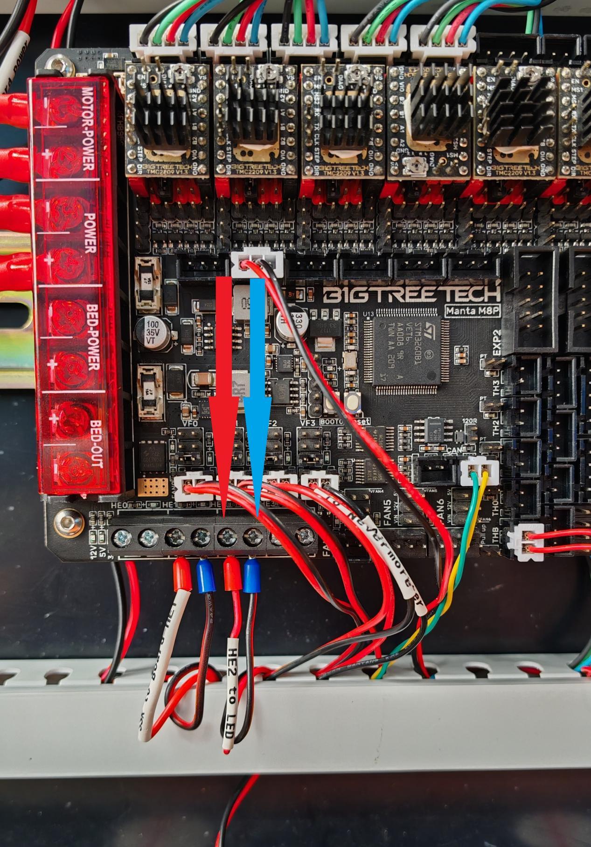
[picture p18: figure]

Filament Runout Sensor:
Take out the sensor and cable as showed below.

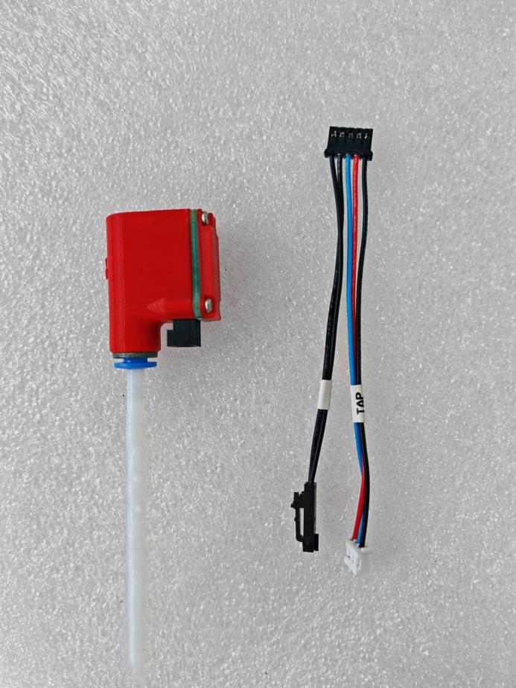
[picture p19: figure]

Plug the cable into below connector on extruder.

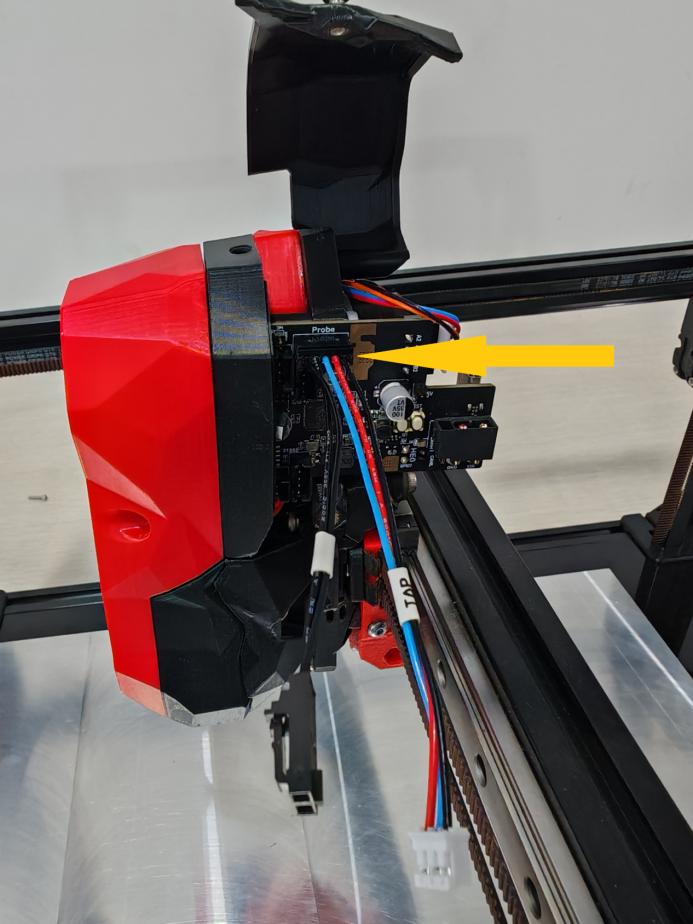
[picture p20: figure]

Plug the wires of TAP to below connector.

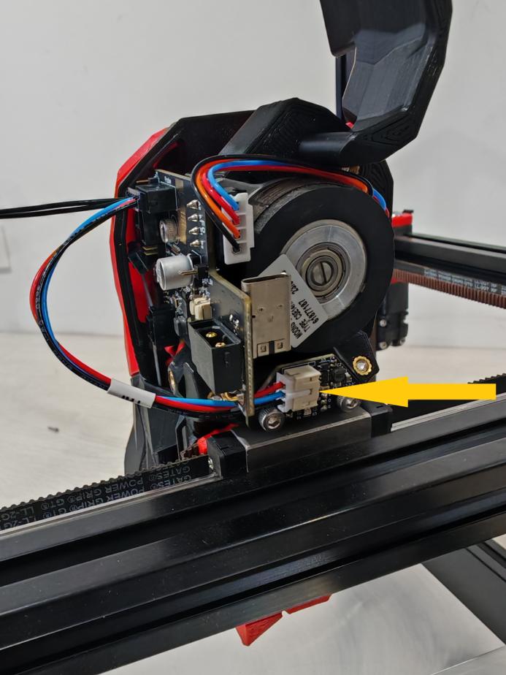
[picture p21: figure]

Pass the wires of filament runout sensor through below hole, then plug it onto sensor directly.

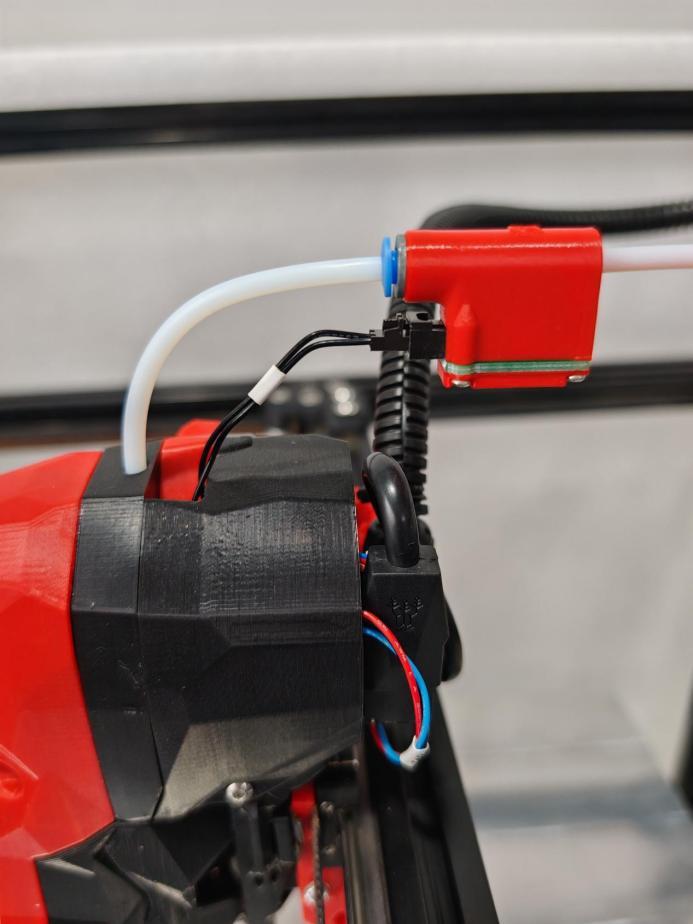
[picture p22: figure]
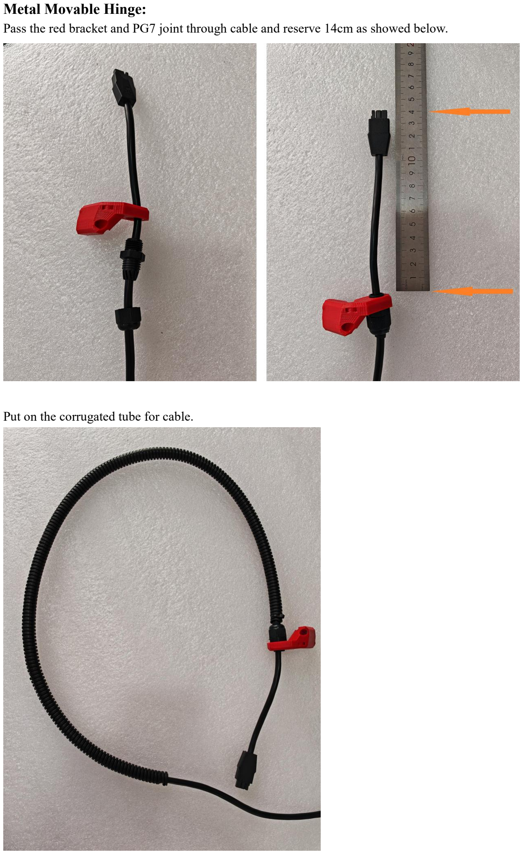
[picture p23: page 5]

Metal Movable Hinge:
Pass the red bracket and PG7 joint through cable and reserve 14cm as showed below.

Put on the corrugated tube for cable.

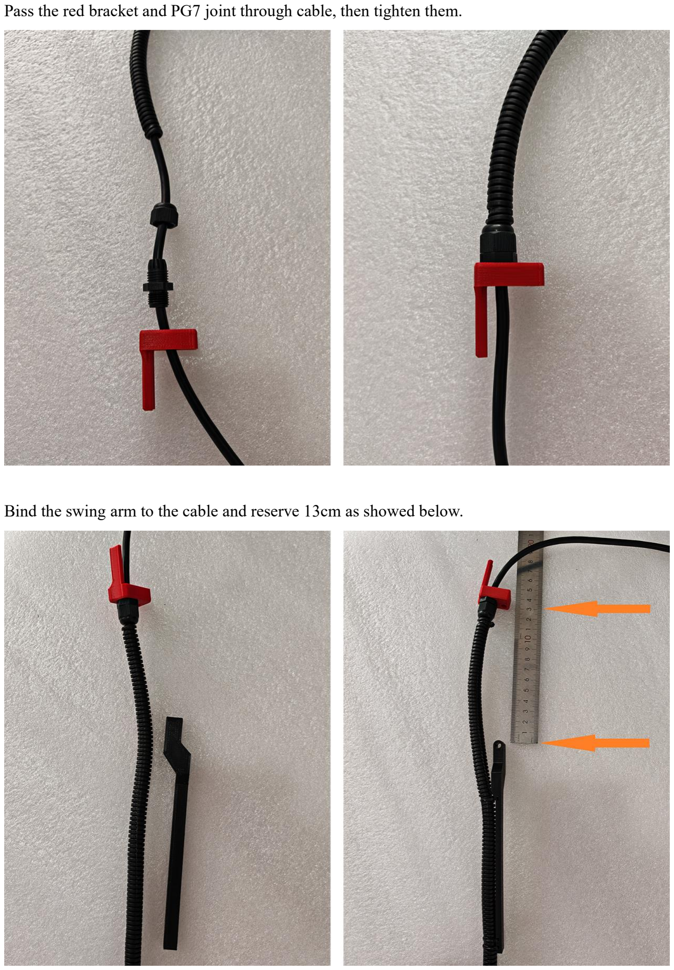
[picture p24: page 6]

Pass the red bracket and PG7 joint through cable, then tighten them.

Bind the swing arm to the cable and reserve 13cm as showed below.

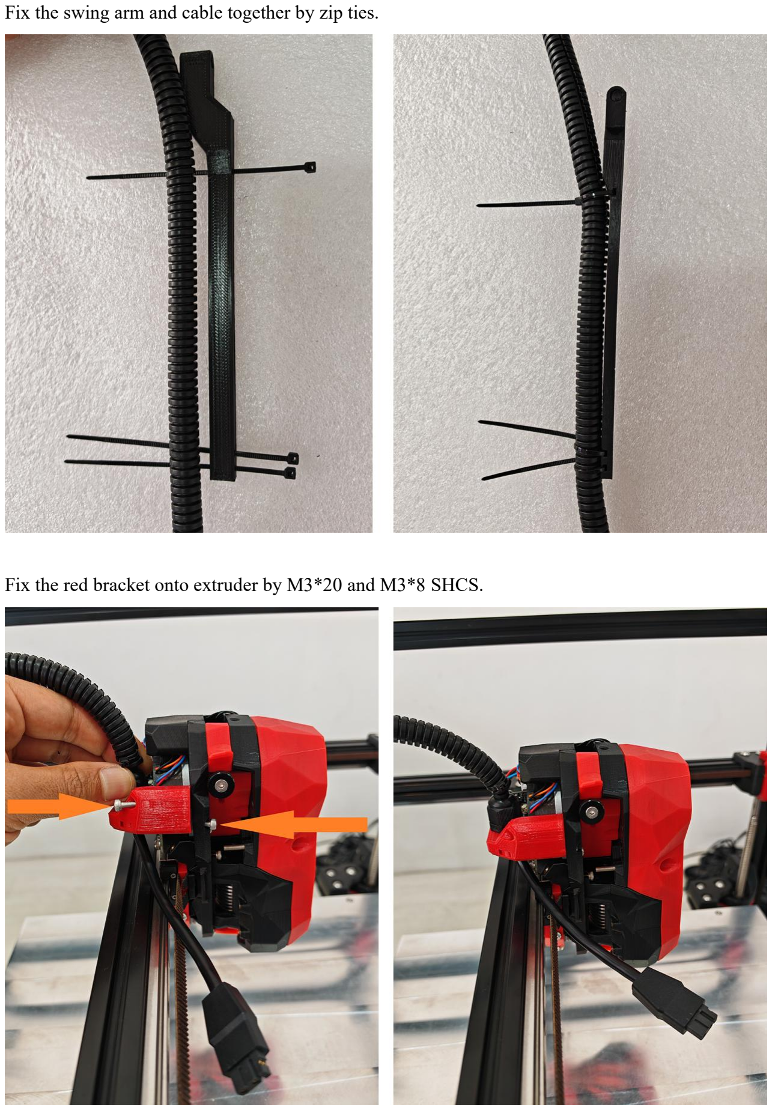
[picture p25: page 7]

Fix the swing arm and cable together by zip ties.

Fix the red bracket onto extruder by M3*20 and M3*8 SHCS.

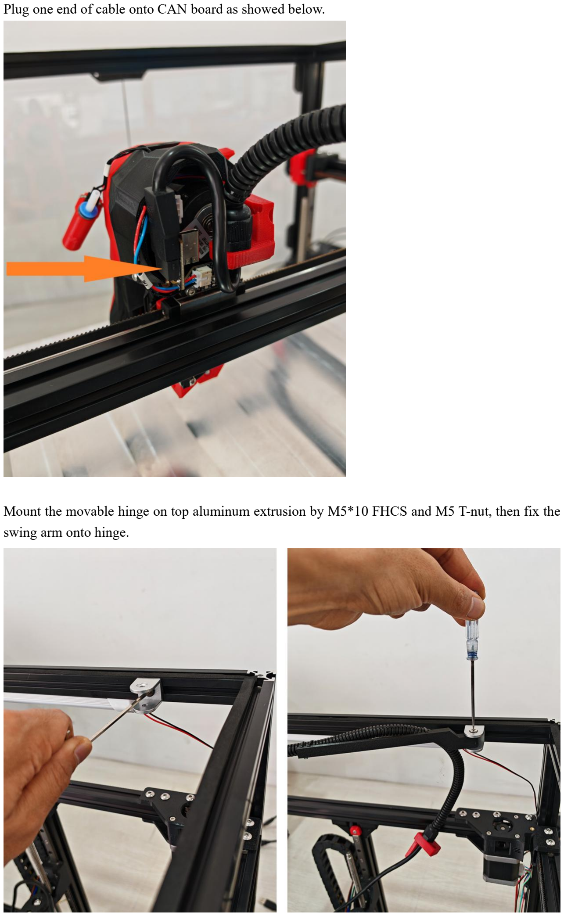
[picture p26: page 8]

Plug one end of cable onto CAN board as showed below.

Mount the movable hinge on top aluminum extrusion by M5*10 FHCS and M5 T-nut, then fix the swing arm onto hinge.

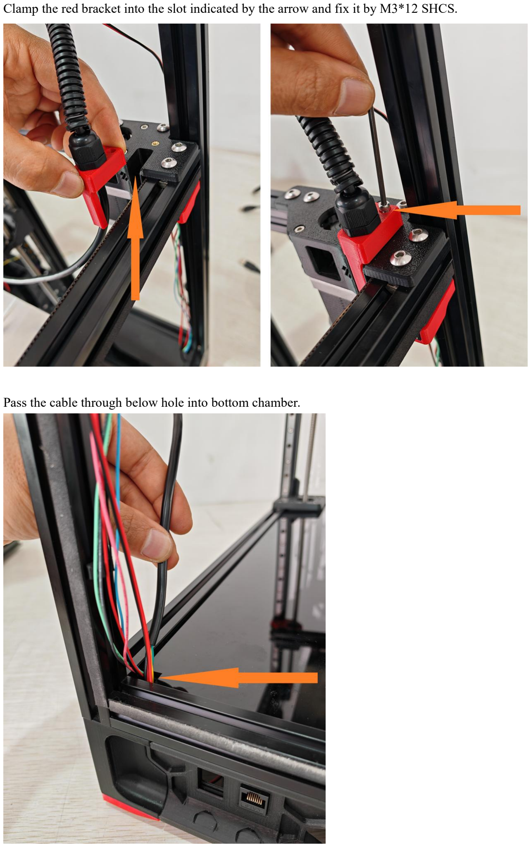
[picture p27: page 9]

Clamp the red bracket into the slot indicated by the arrow and fix it by M3*12 SHCS.

Pass the cable through below hole into bottom chamber.

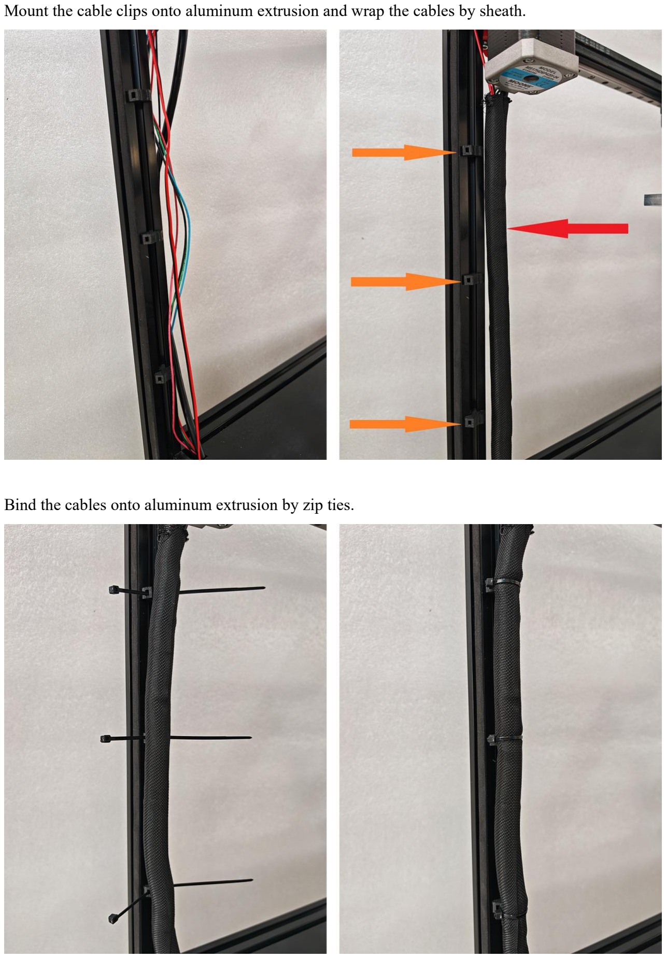
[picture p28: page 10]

Mount the cable clips onto aluminum extrusion and wrap the cables by sheath.

Bind the cables onto aluminum extrusion by zip ties.

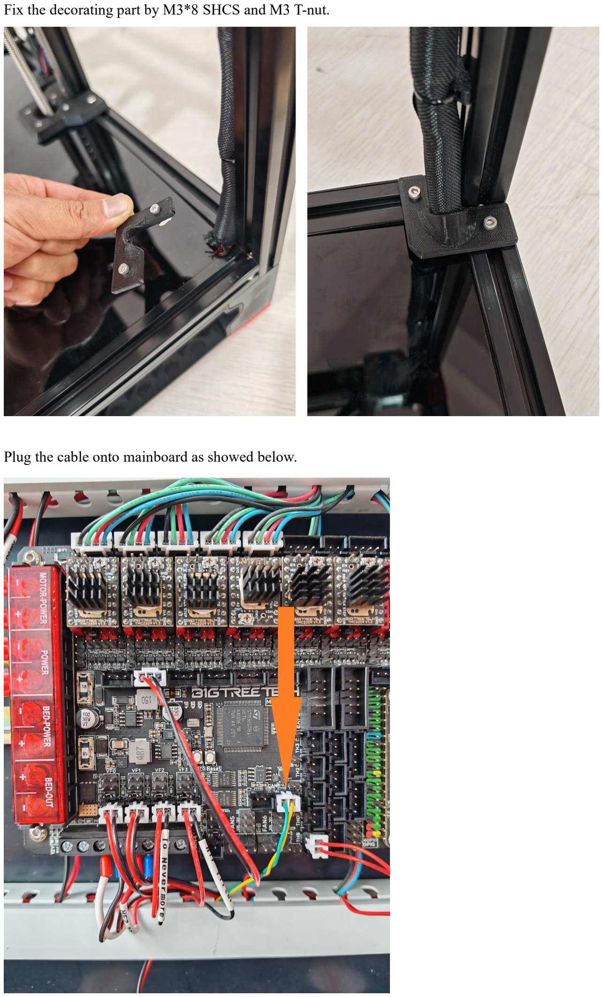
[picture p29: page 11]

Fix the decorating part by M3*8 SHCS and M3 T-nut.

Plug the cable onto mainboard as showed below.

Connect below two wires to power supply, the red wire to “+”, the black wire to “-”.

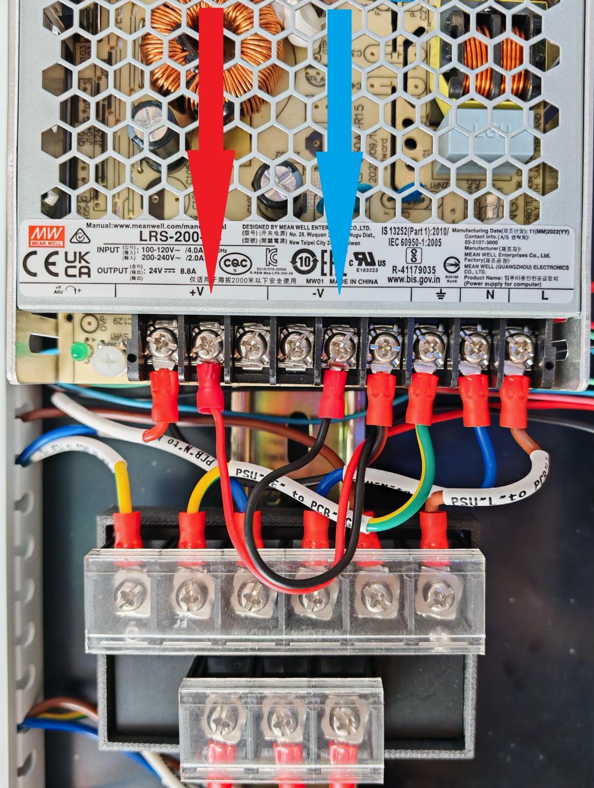
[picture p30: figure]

Nevermore Air Filter:
Iron M3 brass nuts into below holes.

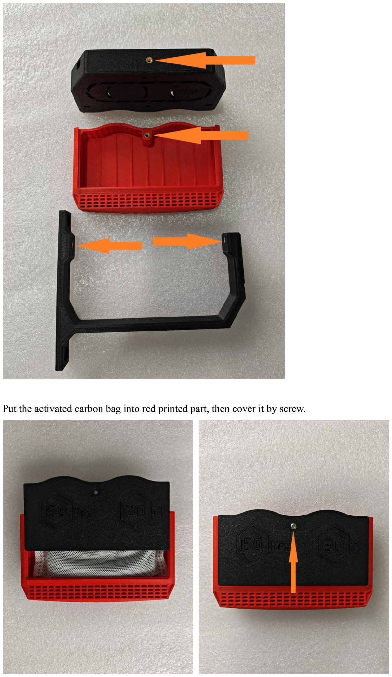
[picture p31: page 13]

Put the activated carbon bag into red printed part, then cover it by screw.

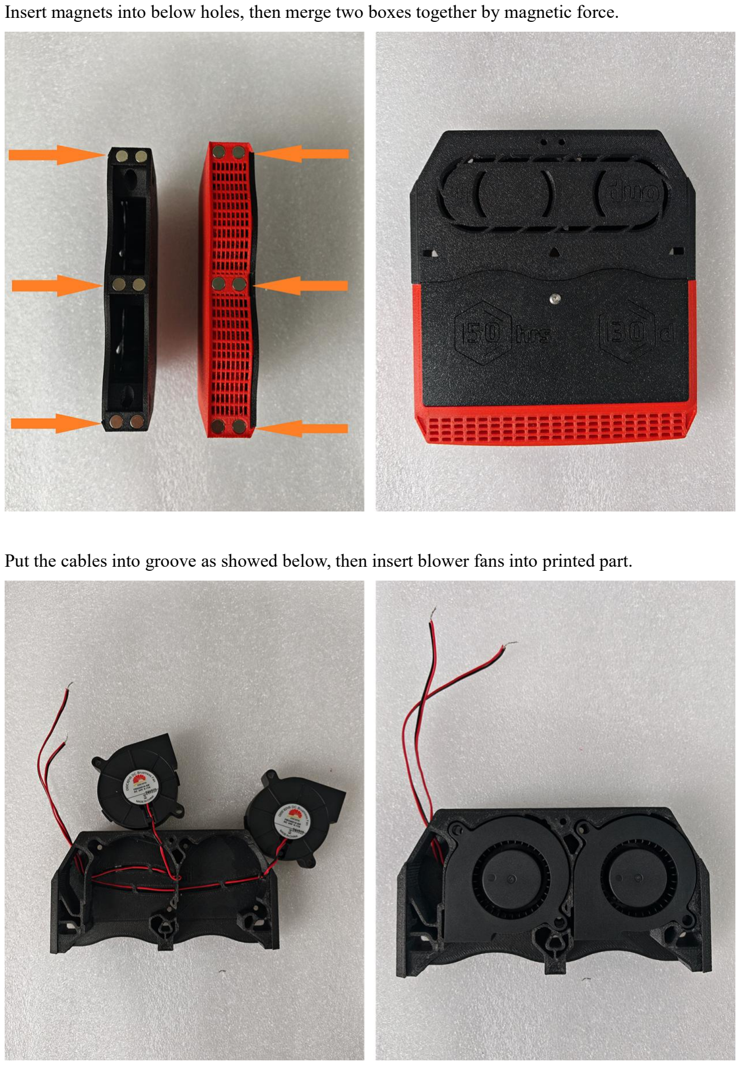
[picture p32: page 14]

Insert magnets into below holes, then merge two boxes together by magnetic force.

Put the cables into groove as showed below, then insert blower fans into printed part.

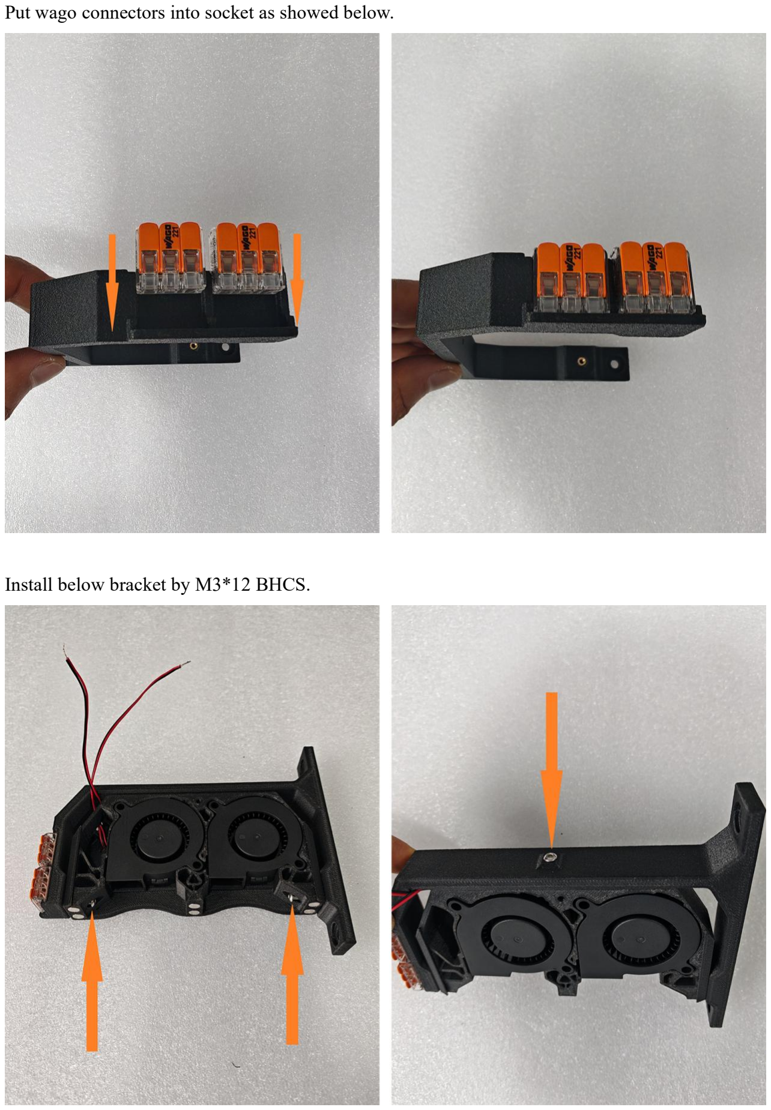
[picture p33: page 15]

Put wago connectors into socket as showed below.

Install below bracket by M3*12 BHCS.

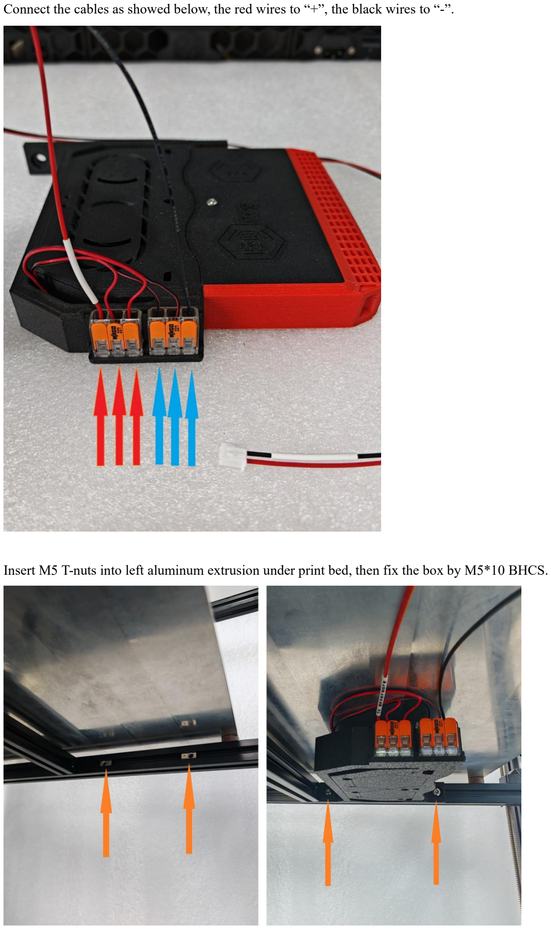
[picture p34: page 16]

Connect the cables as showed below, the red wires to “+”, the black wires to “-”.

Insert M5 T-nuts into left aluminum extrusion under print bed, then fix the box by M5*10 BHCS.

Merge two boxes together by magnetic force.

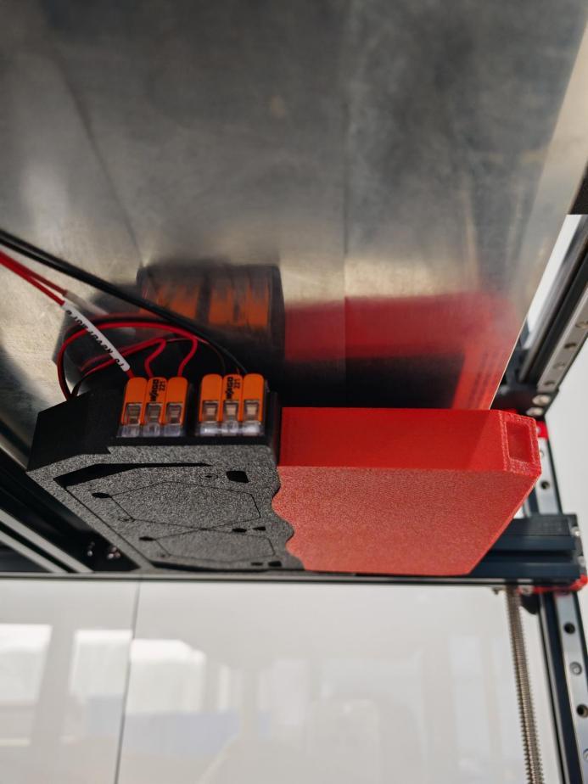
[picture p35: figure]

Pass the cables through chain into bottom chamber.

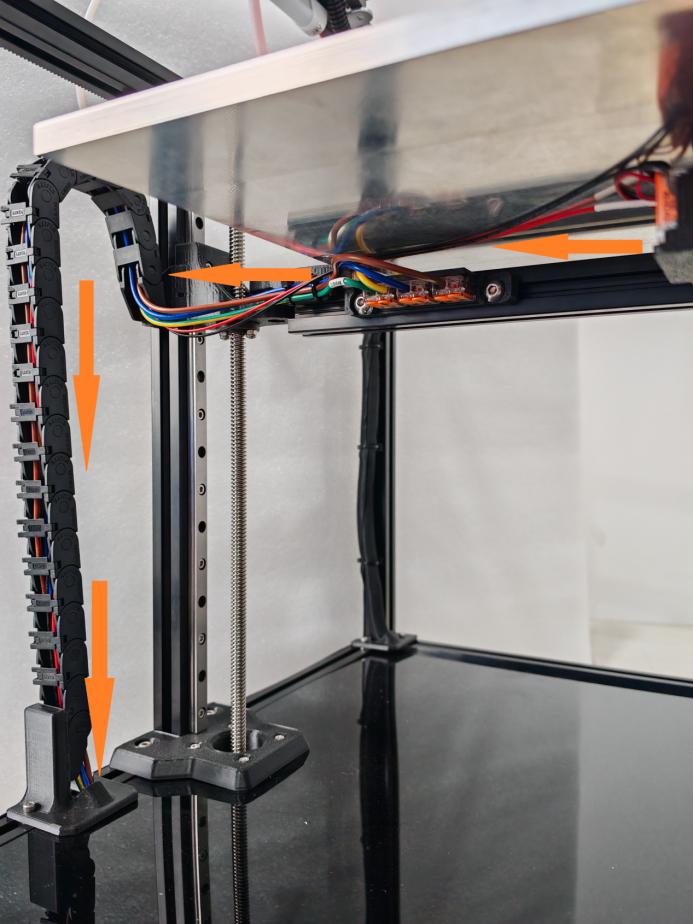
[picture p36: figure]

Finally, plug it onto mother board as showed below.

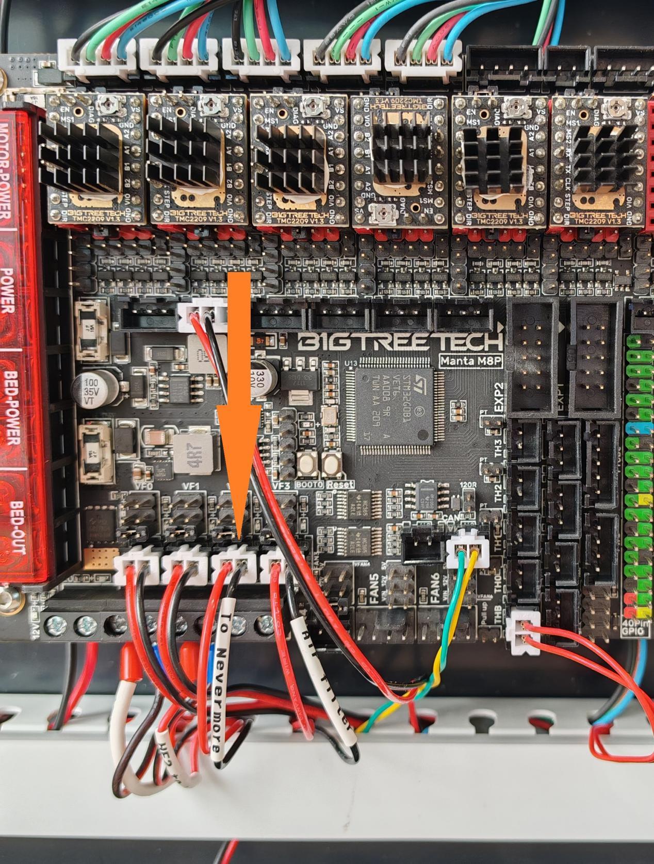
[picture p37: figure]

Referential Links:

Voron Official Build Guide: https://github.com/VoronDesign/Voron-Trident/tree/main/Manual

Stealthburner Extruder:
https://github.com/VoronDesign/Voron-Stealthburner/blob/main/Manual/Assembly_Manual_SB.p df (https://github.com/VoronDesign/Voron-Stealthburner/blob/main/Manual/Assembly_Manual_SB.pdf)

TAP R8 Leveling Sensor:
https://github.com/VoronDesign/Voron-Tap/blob/main/Manual/Assembly_Manual_Tap.pdf

HDMI 5" V1.2 Screen:
https://www.printables.com/model/926845-btt-hdmi5-v12-display-mount-voron

Manta M8P V2.0+CB1 Board:
https://github.com/bigtreetech/Manta-M8P/blob/master/V2.0/BIGTREETECH%20MANTA%20 M8P%20V2.0%20User%20Manual.pdf (https://github.com/bigtreetech/Manta-M8P/blob/master/V2.0/BIGTREETECH%20MANTA%20M8P%20V2.0%20User%20Manual.pdf)

EBB SB2209 CAN(RP2040):
https://github.com/bigtreetech/EBB
https://canbus.esoterical.online/

Umbilical Mount for CAN:
https://www.printables.com/model/326623-voron-trident-wire-cover-w-pg7-cable-gland-adapterhttps://www.printables.com/pl/model/464735-pg7-cnlinko-lp-12-mount-for-sb22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

Nozzle Clean Mod:
https://www.printables.com/model/413177-voron-trident-fixed-nozzle-scubber

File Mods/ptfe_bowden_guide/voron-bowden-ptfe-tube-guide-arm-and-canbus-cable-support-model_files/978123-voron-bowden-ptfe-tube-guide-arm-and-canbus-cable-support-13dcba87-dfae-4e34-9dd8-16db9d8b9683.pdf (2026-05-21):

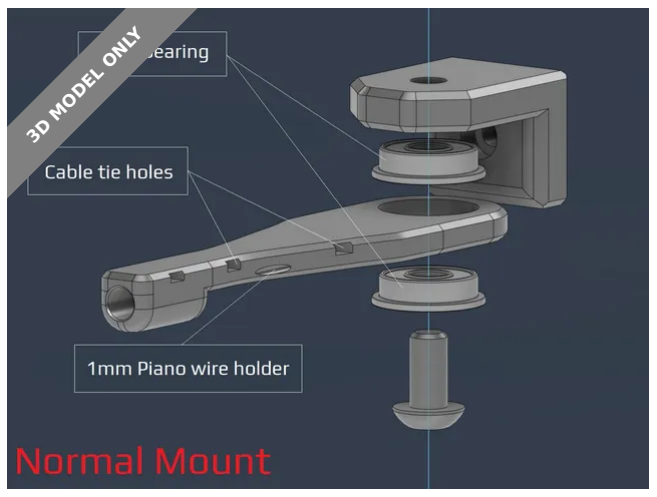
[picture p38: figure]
3D MODEL ONLY

## Summary

Voron PTFE Bowden tube guide and canbus cable holder

3D Printers (https://printables.com/model?categoryId=1) > Voron Parts & Upgrades (https://printables.com/model?categoryId=137)

Tags: | holder | guide | ptfe | tube | bowden | wire | trident
voron | canbus

V2- PTFE bowden tube guide and CANBUS wire support

**** 7NOV24 -Removed a zip tie hole on the long arm's that was a weak point ****

I've made some adjustment after some feedback from the community.

Changes made over V1:

Added a option to have F695 bearings incorporated
Enlarged the tube opening
Added cable/zip tie openings
Added spot for 1mm piano wire if needed.

Galvanic (https://printables.com/@GalvanicGlaze_170963)

## Voron Bowden ptfe tube guide arm and canbus cable support

VIEW IN BROWSER (https://printables.com/model/978123-voron-bowden-ptfe-tube-guide-arm-and-canbus-cable)

updated 28. 2. 2026 | published 28. 2. 2026

•
•
•
•

## Model files

Recommended print settings:

Voron print settings (4 walls, 40% infill and 5 top and bottom layers) Turn off thin walls
Bridge setting: keep only bridges (watch out for bridging for cable tie holes)
0.2mm layers and 0.2mm first layer
No need to adjust for ABS shrinkage

Required Hardware:

M3x8 Bolt and M3 T-nut
M5 bolt to suit option.
Optional M5 nut if you can fit it with the bearing option.
V1 - PTFE bowden tube guide and CANBUS wire support

This is can found inside the zip files and of the initial release

Required Hardware:

M3x8 Bolt and M3 T-nut
M5x10 Bolt or a M5x8/12
Optional 4mm drill bit for cleaning out bowden tube path

About

In my 350 build the PTFE tube kept getting caught so I made this arm to keep it up. The shorter arm works better so I recommend using it instead The setup has also been used by a few user to support their CANBUS wires (zip tied to the reverse bowden)

Install

Drill out bowden guide with 4mm drill bit for a perfect fit (optional) Bolt mount to rear frame with M3x8 and tnut putting the lip at the top Screw arm on with M5x10 (I used a M5x8mm and it works fine) into the plastic allowing the arm to still be able to swivel

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
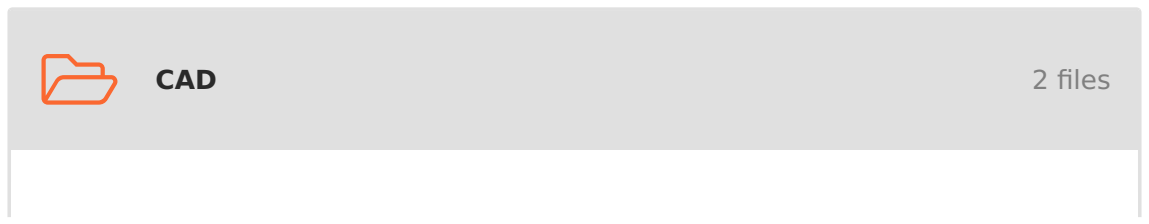
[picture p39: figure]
CAD; 2 files

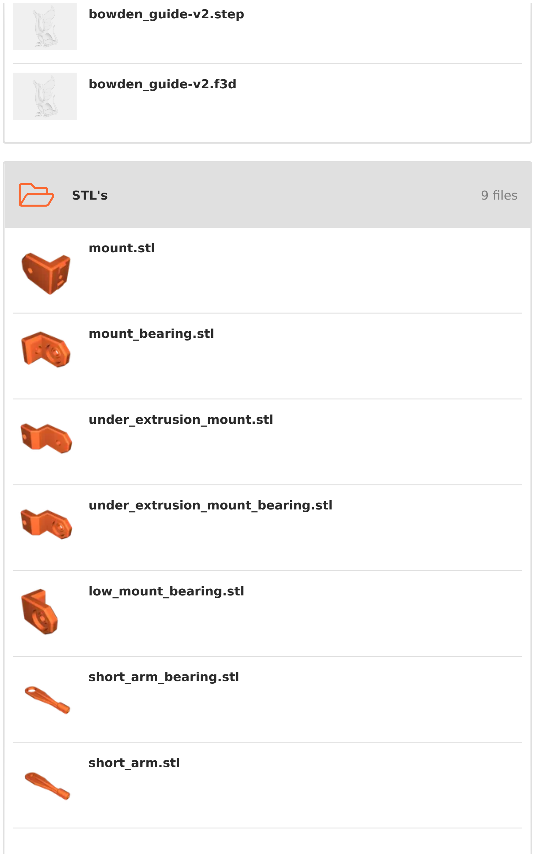
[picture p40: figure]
STL's; 9 files; bowden_guide-v2.step; bowden_guide-v2.f3d; mount.stl; mount_bearing.stl; under_extrusion_mount.stl; under_extrusion_mount_bearing.stl; low_mount_bearing.stl; short_arm_bearing.stl; short_arm.stl

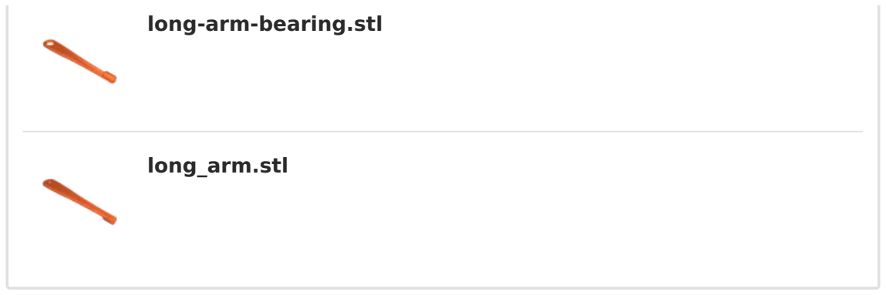
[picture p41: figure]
long-arm-bearing.stl; long_arm.stl

## Other files

## License

This work is licensed under a GNU

General Public License v3.0 (https://www.gnu.org/licenses/gpl-3.0.html)

✖ | Sharing without ATTRIBUTION
✔ | Remix Culture allowed
✔ | Commercial Use
✔ | Meets Open Definition
ℹ | Share under the same license

bowden_guide-v2.3mf

v1.zip

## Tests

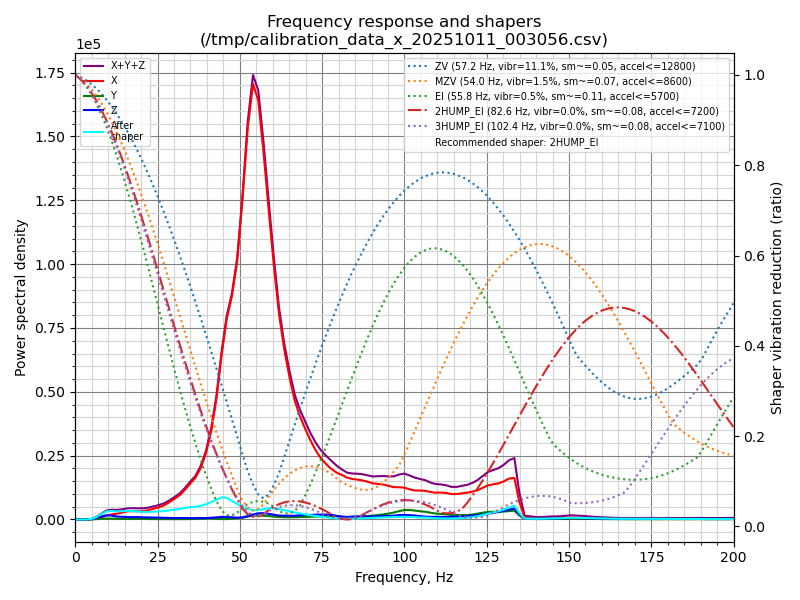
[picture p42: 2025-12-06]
input_shaper/shaper_calibrate_x.png

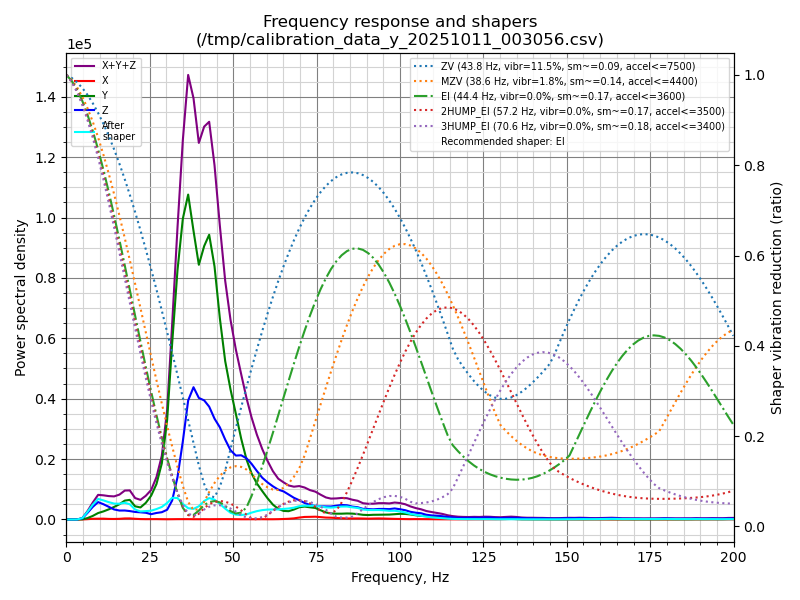
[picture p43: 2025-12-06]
input_shaper/shaper_calibrate_y.png

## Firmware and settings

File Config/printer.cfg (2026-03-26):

[include mainsail.cfg]

[mcu]
canbus_uuid: YOU_DIDNT_CHANGE_ME_YET						# Insert the CANbus-UUID of your Manta from the firmware flashing steps

[mcu EBBCan]
canbus_uuid: YOU_DIDNT_CHANGE_ME_YET						# Insert the CANbus-UUID of your SB2209 RP2040 from the firmware flashing steps

[printer]
kinematics: corexy
max_velocity: 300  
max_accel: 10000
max_z_velocity: 15
max_z_accel: 350
square_corner_velocity: 5.0

[temperature_sensor MCU]
sensor_type: temperature_mcu

[temperature_sensor SoC]
sensor_type: temperature_host

#####################################################################
# 	X/Y Stepper Settings
#####################################################################

## X Stepper on Motor1(B Motor)
[stepper_x]
step_pin: PE6
dir_pin: PE5
enable_pin: !PC14
microsteps: 16
rotation_distance: 40
full_steps_per_rotation:200  #set to 400 for 0.9 degree stepper
endstop_pin: ^EBBCan:gpio24
position_min: 0
##--------------------------------------------------------------------

##	Uncomment below for 250mm build
#position_endstop: 250
#position_max: 250

##	Uncomment for 300mm build
#position_endstop: 300
#position_max: 300

##	Uncomment for 350mm build
#position_endstop: 350
#position_max: 350

##--------------------------------------------------------------------
homing_speed: 25   #Max 100
homing_retract_dist: 5
homing_positive_dir: true

##	Make sure to update below for your relevant driver (2208 or 2209)
[tmc2209 stepper_x]
uart_pin: PC13
interpolate: True
run_current: 0.9
sense_resistor: 0.110
stealthchop_threshold: 0

## Y Stepper on Motor2 (A Motor)
[stepper_y]
step_pin: PE2
dir_pin: PE1
enable_pin: !PE4
microsteps: 16
rotation_distance: 40
full_steps_per_rotation:200  #set to 400 for 0.9 degree stepper
endstop_pin: ^PF3
position_min: 0
##--------------------------------------------------------------------

##	Uncomment for 250mm build
#position_endstop: 250
#position_max: 250

##	Uncomment for 300mm build
#position_endstop: 300
#position_max: 300

##	Uncomment for 350mm build
#position_endstop: 350
#position_max: 350

##--------------------------------------------------------------------
homing_speed: 25  #Max 100
homing_retract_dist: 5
homing_positive_dir: true

##	Make sure to update below for your relevant driver (2208 or 2209)
[tmc2209 stepper_y]
uart_pin: PE3
interpolate: True
run_current: 0.9
sense_resistor: 0.110
stealthchop_threshold: 0

#####################################################################
# 	Z Stepper Settings
#####################################################################

## Z0 Stepper - Front Left on MOTOR3_A
[stepper_z]
step_pin: PB8
dir_pin: PB7
enable_pin: !PE0
# Rotation Distance for TR8x8 = 8, TR8x4 = 4, TR8x2 = 2
# rotation_distance: 8    
microsteps: 32
endstop_pin: probe:z_virtual_endstop
position_max: 250
position_min: -2.5
homing_speed: 8.0 # Leadscrews are slower than 2.4, 10 is a recommended max.
second_homing_speed: 3
homing_retract_dist: 3

##	Make sure to update below for your relevant driver (2208 or 2209)
[tmc2209 stepper_z]
uart_pin: PB9
interpolate: true
run_current: 0.6
sense_resistor: 0.110
stealthchop_threshold: 0

##	Z1 Stepper - Rear  on Motor5
[stepper_z1]
step_pin: PB4
dir_pin: PB3
enable_pin: !PB6
# Rotation Distance for TR8x8 = 8, TR8x4 = 4, TR8x2 = 2
# rotation_distance: 8  
microsteps: 32

##	Make sure to update below for your relevant driver (2208 or 2209)
[tmc2209 stepper_z1]
uart_pin: PB5
interpolate: true
run_current: 0.6
sense_resistor: 0.110
stealthchop_threshold: 0

##	Z2 Stepper - Front Right on Motor6
[stepper_z2]
step_pin: PG13
dir_pin: !PG12
enable_pin: !PG15
# Rotation Distance for TR8x8 = 8, TR8x4 = 4, TR8x2 = 2
# rotation_distance: 8  
microsteps: 32

##	Make sure to update below for your relevant driver (2208 or 2209)
[tmc2209 stepper_z2]
uart_pin: PG14
interpolate: true
run_current: 0.6
sense_resistor: 0.110
stealthchop_threshold: 0

#####################################################################
# 	Extruder
#####################################################################

#	E0 on SB2209
[extruder]
step_pin: EBBCan:gpio18
dir_pin: EBBCan:gpio19
enable_pin: !EBBCan:gpio17
microsteps: 16
rotation_distance: 22.905740611
gear_ratio: 50:10
nozzle_diameter: 0.400
filament_diameter: 1.750
heater_pin: EBBCan:gpio7
control: pid
min_temp: 0
max_extrude_only_distance: 105
max_extrude_cross_section: 2
pid_kp: 57.369
pid_ki: 2.533
pid_kd: 324.854
sensor_type: MAX31865
sensor_pin: EBBCan:gpio9
spi_software_sclk_pin: EBBCan:gpio10
spi_software_mosi_pin: EBBCan:gpio8
spi_software_miso_pin: EBBCan:gpio11
rtd_nominal_r: 100
rtd_reference_r: 430
rtd_num_of_wires: 2

[tmc2209 extruder]
uart_pin: EBBCan:gpio20
run_current: 0.65
stealthchop_threshold: 0

#####################################################################
# 	Bed Heater
#####################################################################

[heater_bed]
heater_pin: PA1
sensor_type: Generic 3950
sensor_pin: PB1
max_power: 1.0
min_temp: 0
max_temp: 115
control: pid
pid_kp: 58.437
pid_ki: 2.347
pid_kd: 363.769

#####################################################################
# 	Probe
#####################################################################

[probe]
pin: ^EBBCan:gpio22
x_offset: 0
y_offset: 0
#z_offset: 0
lift_speed: 30
activate_gcode:
    {% set PROBE_TEMP = 150 %}
    {% set MAX_TEMP = PROBE_TEMP + 5 %}
    {% set ACTUAL_TEMP = printer.extruder.temperature %}
    {% set TARGET_TEMP = printer.extruder.target %}

    {% if TARGET_TEMP > PROBE_TEMP %}
        { action_respond_info('Extruder temperature target of %.1fC is too high, lowering to %.1fC' % (TARGET_TEMP, PROBE_TEMP)) }
        M109 S{ PROBE_TEMP }
    {% else %}
        # Temperature target is already low enough, but nozzle may still be too hot.
        {% if ACTUAL_TEMP > MAX_TEMP %}
            { action_respond_info('Extruder temperature %.1fC is still too high, waiting until below %.1fC' % (ACTUAL_TEMP, MAX_TEMP)) }
            TEMPERATURE_WAIT SENSOR=extruder MAXIMUM={ MAX_TEMP }
        {% endif %}
    {% endif %}

#####################################################################
# 	Fan Control
#####################################################################
[fan]
pin: EBBCan:gpio13

[heater_fan hotend_fan]
pin: EBBCan:gpio14
heater: extruder
heater_temp: 70.0


[fan_generic nevermore]
##	Print Cooling Fan - CNC_FAN0
pin: PF8
kick_start_time: 0.5
off_below: 0.10

[controller_fan controller_fan_1]
##	Hotend Fan - CNC_FAN1
pin: PF9
max_power: 1.0
kick_start_time: 0.5
fan_speed: 0.66


[heater_fan controller_fan_2]
##	Controller fan - CNC_FAN2
pin: PF6
kick_start_time: 0.5
heater: heater_bed
heater_temp: 80
fan_speed: 0.66

[fan_generic exhaust_fan]
#	Exhaust fan - CNC_FAN0
pin: PF7
max_power: 1.0
shutdown_speed: 0.0
kick_start_time: 0.5

#####################################################################
# 	LED Control
#####################################################################

[neopixel toolhead_light]
pin: EBBCan:gpio16
chain_count: 3
color_order: GRBW

[output_pin caselight]
#Chamber Lighting - HE3 Connector
pin: PA3
pwm:true
shutdown_value: 0
cycle_time: 0.01

#####################################################################
# 	Homing and Gantry Adjustment Routines
#####################################################################

[idle_timeout]
timeout: 3300

[safe_z_home]
##--------------------------------------------------------------------

##	Uncomment below for 250mm build
#home_xy_position: 125,125

##	Uncomment below for 300mm build
#home_xy_position: 150,150

##	Uncomment below for 350mm build
#home_xy_position: 175,175

##--------------------------------------------------------------------
speed: 100
z_hop: 10

[z_tilt]

##--------------------------------------------------------------------
## Uncomment below for 250mm build
#z_positions:
#    -50, 18
#    125, 298
#    300, 18
#points:
#    30, 5
#    125, 195
#    220, 5

## Uncomment below for 300mm build
#z_positions:
#   -50, 18
#   150, 348
#   350, 18
#points:
#   30, 5
#   150, 245
#   270, 5

## Uncomment below for 350mm build
#z_positions:
#   -50, 18
#   175, 398
#   400, 18
#points:
#   30, 5
#   175, 295
#   320, 5

##--------------------------------------------------------------------

speed: 200
horizontal_move_z: 10
retries: 5
retry_tolerance: 0.0075


[bed_mesh]
mesh_min: 10,10
##--------------------------------------------------------------------

##	Uncomment below for 250mm build
#mesh_max: 240,240

##	Uncomment below for 300mm build
mesh_max: 290,290


##	Uncomment below for 350mm build
#mesh_max: 340,340

##--------------------------------------------------------------------



########################################
# EXP1 / EXP2 (display) pins
########################################
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

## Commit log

2025-09-27 sorted and downloaded mod stuff
    [pcb_din_clip_x3.stl]
2026-03-26 sorted and downloaded all installed mods
    [Brackets_2020.stl, Classic__spool_holder.stl, Flex+Plate+Stops.stl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]
2026-05-21 new Mods
    [Voron+Fridge+Door+Light+Switch.stl, Wago 221-413 3-Way Mount (x2).stl, [a]_Tap_Center_r8.stl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]
